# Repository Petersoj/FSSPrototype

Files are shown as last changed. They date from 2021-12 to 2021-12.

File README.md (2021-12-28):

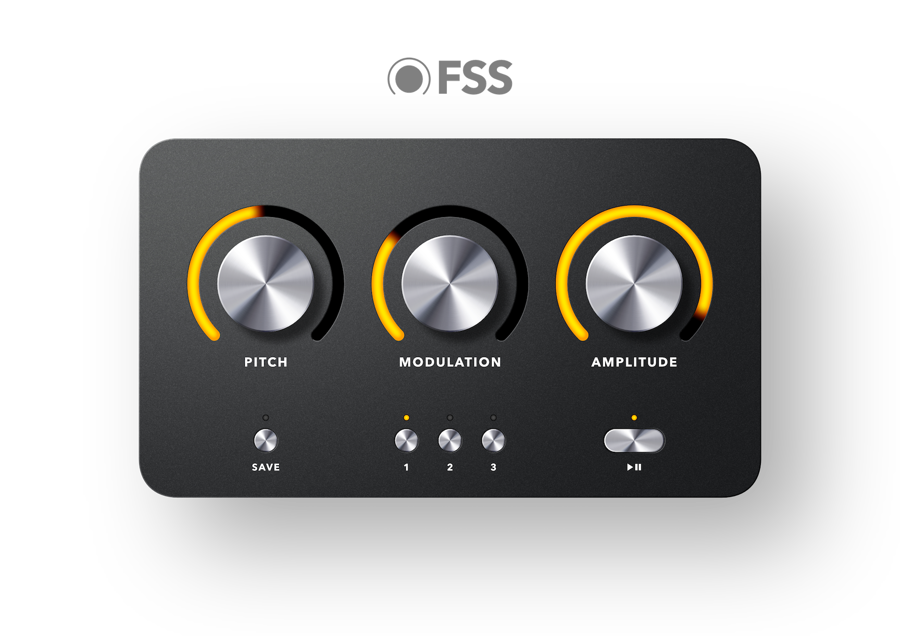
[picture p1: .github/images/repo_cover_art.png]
FSS prototype top-panel concept
<p align="center"></p>

# Fully-Synchronized Synthesizer (FSS) Prototype

This FSS prototype demonstrates the future of interfacing with a music synthesizer. Musicians often switch between programs on their synth as part of their creative process when experimenting with different sounds. However, the control knobs on their synth can't dynamically update to visually display the true value of that knob when switching between programs. This FSS prototype solves this issue by providing program-synchronized ring displays surrounding control knobs, along with internal components housed in a beautiful chassis, and interfaced with via a single USB cable. This repository contains various source files, design files, datasheets, and documentation relevant to the development of this prototype. This prototype serves as the final project for the Computer Design Laboratory ECE 3710 class at The University of Utah for Group 2. As a requirement for this class, this final project uses the [`CompactRISC16`](https://github.com/Petersoj/CompactRISC16) CPU and assembler that our group built as well. This CPU runs on an FPGA and executes our custom assembly code which is responsible for the FSS interface logic and communication. The FPGA board interfaces with the FSS prototype via I2C using a braided USB cable with the D+/D- pins adapted to be the SCL and SDA pins.

## Authors
- Jacob Peterson
- Brady Hartog
- Isabella Gilman
- Nate Hansen

## How This Repository is Organized
- [`.formatter/verilog/`](.formatter/verilog/) contains the Verilog source code formatter. More info on it [here](https://github.com/Petersoj/FSSPrototype#verilog-source-formatting-for-this-repository).
- [`CompactRISC16/`](https://github.com/Petersoj/CompactRISC16) is a git submodule of our custom CompactRISC16 (CR16) processor repository. Our FSS prototype firmware runs on this custom CR16 processor.
- [`assets/`](assets/) contains various asset files such as SolidWorks sketches and parts, dimension drawings for laser and water jet cutting, schematic and PCB files for our Main board and External board, pictures, etc.
- [`docs/`](docs/) contains our final project reports and Bill of Materials (BOM). Our final report is located [here](docs/Reports/Final%20Report/Final%20Report.pdf).
- [`resources/bram_init/`](resources/bram_init/) contains block RAM (BRAM) initialization files encoded in UTF-8 hexadecimal characters.
- [`resources/pin_assignments/`](resources/pin_assignments/) contains exported CSVs of pin assignments for the various Verilog top modules in this repository.
- [`src/asm/`](src/asm/) contains assembly source code files written in accordance with our custom CR16 ISA. More info on [`fss.asm`](src/asm/fss.asm) (the main program/firmware of our FSS prototype) can be found [here](https://github.com/Petersoj/FSSPrototype#assembling-fssasm).
- [`src/v/rtl/`](src/v/rtl/) contains the Verilog and SystemVerilog RTL code for our FSS prototype.
  - [`fss_top.sv`](src/v/rtl/fss_top.sv) instantiates BRAM, the External Memory interface module, and the CR16 processor. Additionally, it contains some logic to display various values on the 7-segment displays on the FPGA board and allows a user to address into BRAM using slide switches.
  - [`ext_mem.sv`](src/v/rtl/ext/ext_mem.sv) is the External Memory interface module which contains memory-mapping logic and instantiates the two peripherals that the FSS prototype requires: [`clock_divided_counter.sv`](src/v/rtl/ext/peripheral/clock_divided_counter.sv) which is used as a microsecond counter and [`i2c_bus.sv`](src/v/rtl/ext/peripheral/i2c_bus.sv) which is used to interface with the open-drain SCL and SDA bus lines for I2C communication.
- [`src/v/tb/`](src/v/tb/) contains the Verilog and SystemVerilog testbench code for testing the various FSS prototype RTL modules.

## Project Videos
We wanted to create a professional video in the form of a product advertisement showing the beauty we captured in the FSS prototype's design. That video is available [here](https://www.youtube.com/watch?v=7kbVaDARXf8). Additionally, a demo video showing the basic usage and functional overview of the FSS prototype is available [here](https://www.youtube.com/watch?v=SxbYaiAhI7I).

## Project Photos
<p align="center">
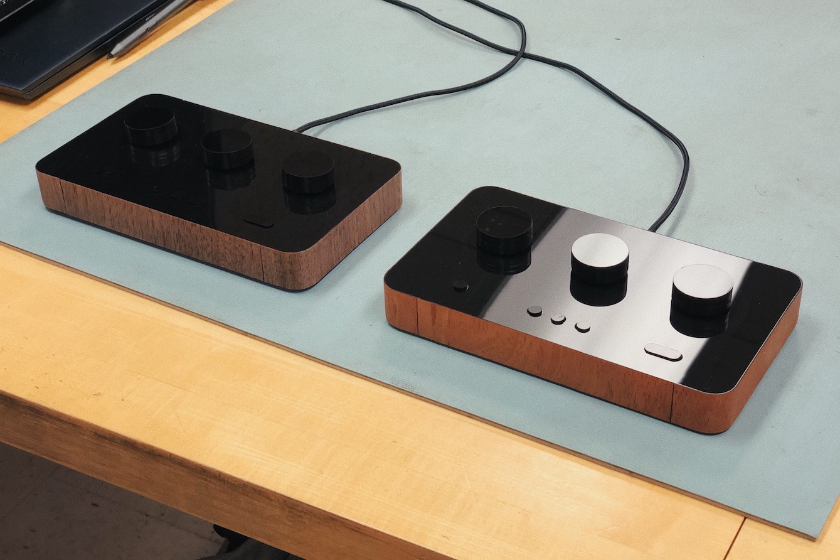
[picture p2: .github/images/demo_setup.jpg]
  
</p>
<p align="center">
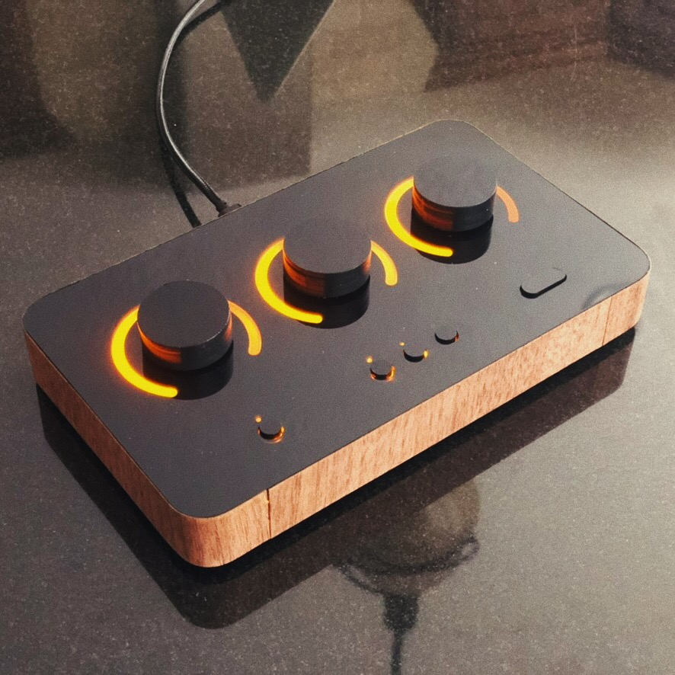
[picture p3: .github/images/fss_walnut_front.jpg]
  
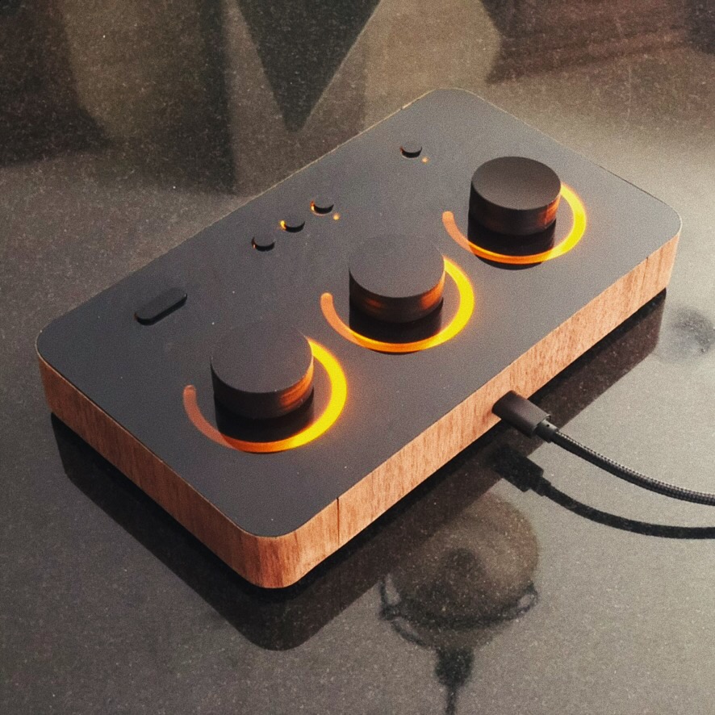
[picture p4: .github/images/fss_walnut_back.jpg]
  
</p>
<p align="center">
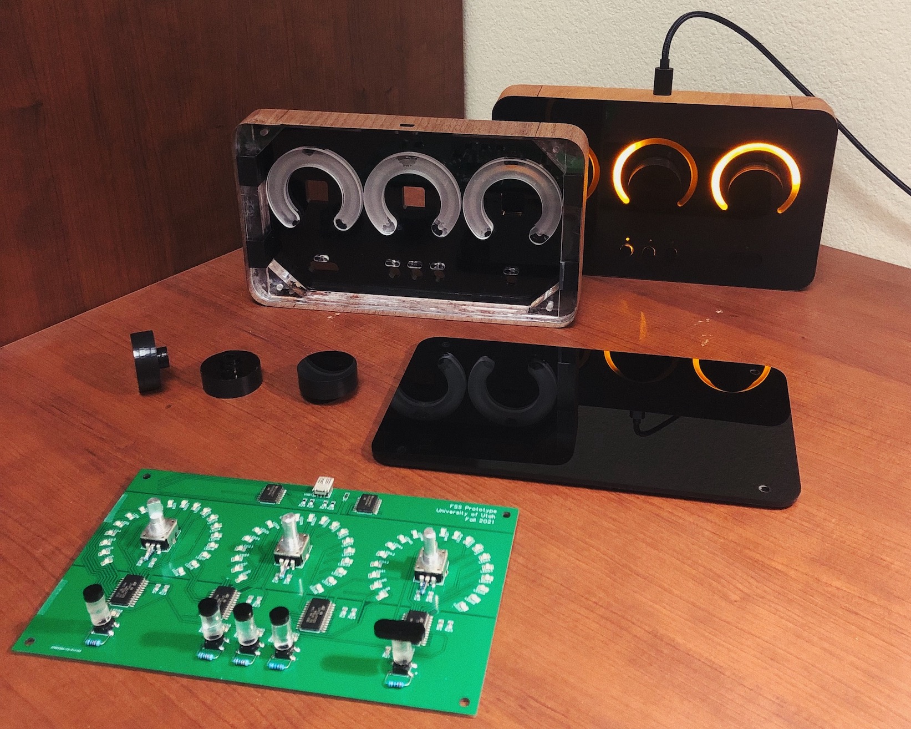
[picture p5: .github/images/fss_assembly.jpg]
  
</p>

## Assembling [`fss.asm`](src/asm/fss.asm)
[`fss.asm`](src/asm/fss.asm) contains the assembly source code for the firmware of the FSS prototype. This assembly source code is compiled to a [machine code data file](resources/bram_init/fss.dat) which is loaded into BRAM upon FPGA programming. To assemble/compile `fss.asm`, follow these steps:
1. Ensure that the `CompactRISC16` submodule has been initialized and updated via: `git submodule update --init`
2. Run the assembler via:
   ```
   ./CompactRISC16/assembler/assembler src/asm/fss.asm -o resources/bram_init/fss.dat -p 4096 -v 0 -b HEX
   ```
  * `-p 4096` sets the max padding lines to 4096 (which is 2^12 due to `fss_top` instantiating `bram` with a 12-bit address space) in the output machine code file
  * `-v 0` sets the padding line value to 0 (which initializes empty BRAM to all zeros) in the output machine code file
  * `-b HEX` sets the number base to hexadecimal in the output machine code file
3. More info about the CR16 assembler used in this project can be found [here](https://github.com/Petersoj/CompactRISC16#assembler).

## Verilog Source Naming Conventions and Format
- File names, module names, and wire/reg assignment names should be snake case (e.g. `my_verilog_module.v`)
- Testbench modules and file names should be appended with a `_tb` (e.g. `my_verilog_module_tb.v`)
- Top level modules and file names should be appended with a `_top` (e.g. `my_verilog_module_top.v`)
- There should only be one module per source code file
- Module instantiations should use uppercase named port lists with inputs prepended with `I_` and outputs prepended with `O_` (e.g. `my_verilog_module(.I_INPUT_1(my_input_1), .O_OUTPUT_1(my_output_1));`)
- Module signatures and bodies should use parameters instead of hard-coding constants. When defining the parameters for a module instantiation or for a module signature, the parameter list should start on the next line, but if there is only one parameter, it should be defined on the same line as the module instantiation or signature (same goes for the port list of a module).
- The port list in module signatures should contain `input` and `output` port direction declarations, as opposed to those port direction declarations being placed in the body of the module.
- Consecutive single line comments should always be aligned with eachother if there are no lines between them.
- If there are 2 or more consecutive lines (including no comments between the consecutive lines) that assign a `parameter`, `localparam`, `wire`, or `reg` to a constant or to a single-line expression, then the equals signs in those lines should be aligned.
- If a single-line expression/assignment needs to be split into multiple lines, then the following lines should be further indented by 8 spaces, or if the subsequent lines can fit within the 100 character column limit, then the subsequent lines should be further indented until they are aligned to the expression/assigment on the first line.
- No line should be greater than 100 characters.
- Use non-blocking assignments (e.g. `<=`) in sequential `@always` blocks and blocking assignments (e.g. `=`) in combinational `@always` blocks.
  - An `@always` block is sequential if it is sensitive to the `posedge` or `negedge` of an input signal, whereas it is combinational if it is sensitive to signals without the `posedge` or `negedge` modifier included in the sensitivity list.
- Module sections should generally follow the following format, from top of file to bottom of file:
  - Module signature with parameter list, then input wires, then output reg/wires
  - `localparam`s that defines constants for the rest of the module
  - Internal register and wire declarations
    - Prepend reg/wire names with `q_` to represent a 'current state' register/wire and `n_` to represent a 'next state' register/wire
  - Output mapping `assign` statements which map internal wires/registers with module output wires/registers
  - RTL logic with `assign` statements for all internal wires which generally consist of ternary operators
  - Module instantiations using named port lists in the instantiation signature and a module instance name that is the same as the module name (or a name that's more concise and applicable to the instantiation), but with `i` prepended
  - Clock `@always` blocks which generally should only include `posedge I_CLK` in the sensitivty list
  - Other `@always` (such as internal finite state machines) or `task` blocks

## Verilog Source Formatting For This Repository
To format verilog source code, use the [`istyle-verilog-formatter`](https://github.com/thomasrussellmurphy/istyle-verilog-formatter) tool via the `format` script:
```
.formatter/verilog/format <paths to files or directories>
```
For example, to recursively format Verilog source files in the `src` directory, use the following command:
```
.formatter/verilog/format src
```
The [`istyle-verilog-formatter`](https://github.com/thomasrussellmurphy/istyle-verilog-formatter) is used as a submodule in the [`.formatter/verilog`](.formatter/verilog) directory. Either clone this repository with `git clone --recurse-submodules` or use `git submodule init; git submodule update` to clone the `istyle-verilog-formatter` repository into the `.formatter/verilog` directory so that the `format` script can run properly. The `format` shell script will run `make` if the `iStyle` binary is not already present in the `istyle-verilog-formatter` directory. Note: you may need to make the script executable via: `chmod 755 .formatter/verilog/format`.

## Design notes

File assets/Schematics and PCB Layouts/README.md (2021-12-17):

The Breakout and Main schematic and PCB was creating using [easyEDA](https://easyeda.com).

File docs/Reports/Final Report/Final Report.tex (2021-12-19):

% Section Delegation Mapping:
%
% --------------------> Brady
% Introduction
% Overview
% --------------------
%
% Hardware
%   -FPGA Board ----------------> Nate
%   -Breakout Box --------------> Isabella
%   -FSS PCB -------------------> Jacob
%   -FSS Housing ---------------> Brady & Isabella
%
% CR16 Processor --------------->Nate
%
% --------------------> Jacob
% Peripheral Interfacing
% Assembler
% --------------------
%
% Firmware --------------------> Jacob & Nate
% Lessons Learned -------------> Everyone
%
% --------------------> Isabella
% About the Team
% Conclusion and Future Work
% --------------------

\documentclass[conference]{IEEEtran}
\usepackage{amsmath,amssymb,amsfonts}
\usepackage{algorithmic}
\usepackage{graphicx}
\usepackage{geometry}
\usepackage{textcomp}
\usepackage{xcolor}
\usepackage{array}
\usepackage{ragged2e}
\usepackage{multirow} % For multirows in tables
\usepackage{float} % Appending the [H] option forces the placement of a figure in the place it's in the code
\usepackage[numbers]{natbib} % For integration with bibliography commands
\usepackage{pdfpages}
\usepackage{hyperref}
\usepackage{chngpage}
\usepackage[utf8]{inputenc}
\usepackage{listings}

\usepackage{xparse}
\NewDocumentCommand{\code}{v}{%
\texttt{\textcolor{black}{#1}}%
}

\hypersetup{
    colorlinks=true,
    linkcolor=blue,
    filecolor=magenta,
    urlcolor=cyan,
    citecolor=magenta
}

\def\BibTeX{{\rm B\kern-.05em{\sc i\kern-.025em b}\kern-.08em
    T\kern-.1667em\lower.7ex\hbox{E}\kern-.125emX}}

\geometry{
    a4paper,
    left=0.5in,
    top=0.5in,
    right=0.5in,
    bottom=0.5in
}

\begin{document}

\begin{titlepage}
\begin{adjustwidth}{+1in}{+1in}
\begin{center}
    \vspace*{6.5cm}
    \Huge
    \textbf{Final Report: The Fully-Synchronized Synthesizer (FSS) Interface Prototype}

    \vspace{1cm}
    \LARGE
    Computer Design Laboratory ECE 3710\\
    Fall 2021\\
    The University of Utah

    \vspace{1cm}

    \normalsize
    \centering
    \begin{adjustwidth}{-1.5in}{-1.5in} % Adjust the L and R margins by 1 inch
    \begin{center}
        \begin{tabular}{ c c c c }
        \centering
        Jacob Peterson & Brady Hartog & Isabella Gilman & Nate Hansen\\
        \textit{Computer Engineering 2022} & \textit{Computer Engineering 2022} & \textit{Computer Engineering 2023} & \textit{Computer Engineering 2023}\\
        \textit{University of Utah} & \textit{University of Utah} & \textit{University of Utah} & \textit{University of Utah}\\
        Salt Lake City, UT & Salt Lake City, UT & Salt Lake City, UT & Salt Lake City, UT\\
        \end{tabular}
    \end{center}
    \end{adjustwidth}
\end{center}
\end{adjustwidth}
\end{titlepage}

\begin{abstract}
We present the design and implementation of a small-scale prototype for a fully-synchronized synthesizer (“FSS”) interface. The prototype is designed to address a major drawback of contemporary musical synthesizers. As a proof of concept for an innovative user interface, the prototype casts a vision for a more versatile and powerful synthesizer for the musical artists of tomorrow. Pursuant to the course objectives of ECE 3710, the principal component of the prototype is an Intel Cyclone V FPGA. This report chronicles our process of programming and interfacing with the FPGA as well as crafting a hardware system to deliver a prototype with a highly intentional and interactive user experience.
\end{abstract}

\section{Introduction}

In 1978 the music technology firm Sequential Circuits introduced the Prophet-5 musical synthesizer. Prophet-5 was among the world’s first \textit{fully-programmable} synthesizers, meaning that every controllable parameter could be stored in user-defined programs. Full programmability was a major milestone in the history of the synthesizer, and Prophet-5 would set the precedent of synthesizer design for decades to come.

In fact, over 40 years later, Prophet-5 remains the archetype of modern hardware synthesizers. Whereas the fully-programmable paradigm of Prophet-5 is highly useful, it suffers a major drawback. Fig. \ref{fig:param_analog} illustrates the drawback. In the fully-programmable paradigm, each parameter has both a \textit{physical value} and an \textit{active value}. The physical value is the value indicated by the position of the dial. The active value is set either by: 1) changing the position of the dial (in which case it is the same as the physical value); or by 2) recalling a user-defined program. Naturally, recalled values do not necessarily match—and in practice seldom do match—the physical values of the dials. We say that parameters controlled in this way are \textit{unsynchronized}.

\begin{figure}[bhtp]
    \centering
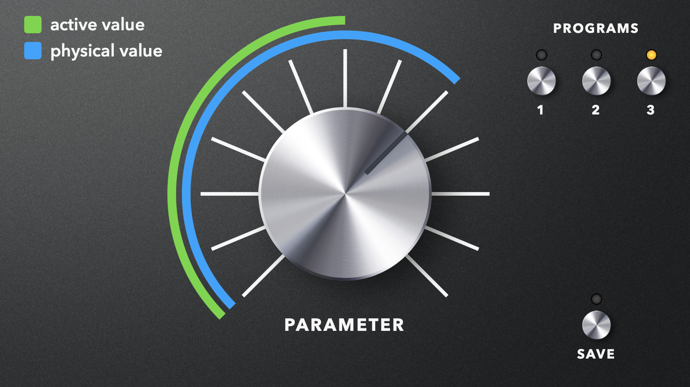
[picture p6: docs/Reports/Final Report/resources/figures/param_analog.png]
    
    \caption{The drawback with traditional, analog level meters. The physical and active values are out of sync!}
    \label{fig:param_analog}
\end{figure}

The drawback described above assumes the use of traditional, analog level meters as shown in Fig. \ref{fig:param_analog}. Fig. \ref{fig:param_digital} depicts a proposed alternative to the traditional level meter. This level meter consists of an LED ring display with digital control. By leveraging digital control, the level meter can display the active value of the parameter at all times, whether it is set by changing the dial or by recalling a program. We say that a parameter controlled in this way is \textit{synchronized}.

\begin{figure}[bhtp]
    \centering
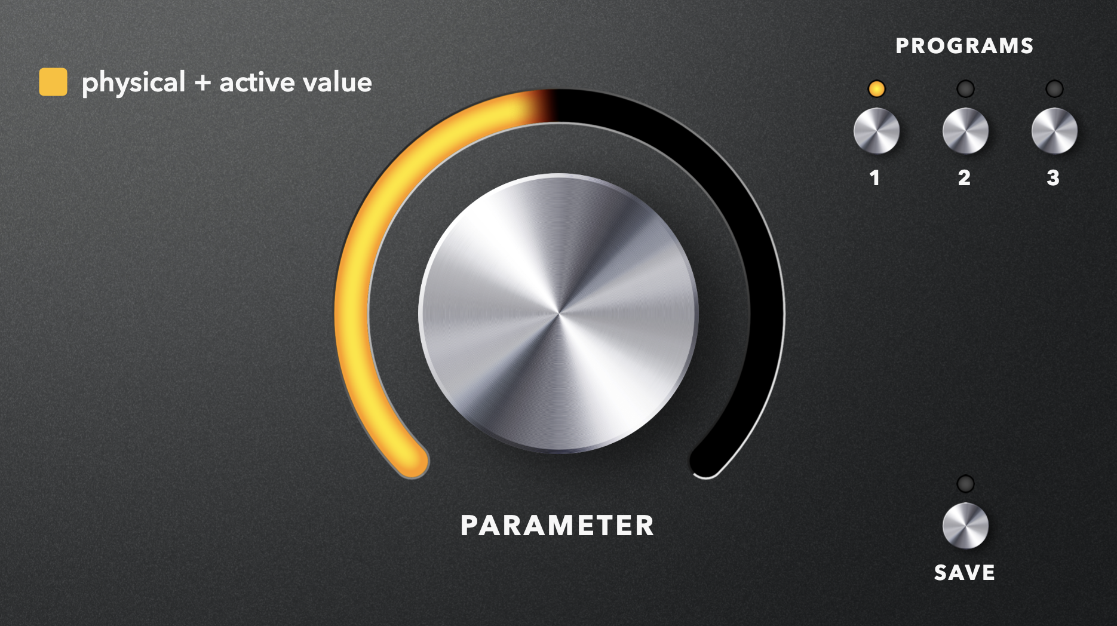
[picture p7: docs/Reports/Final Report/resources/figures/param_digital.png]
    
    \caption{The proposed digital level meter to implement synchronized parameters.}
    \label{fig:param_digital}
\end{figure}

We envision a musical synthesizer for which every parameter on the control panel is synchronized; such would be a \textit{fully-synchronized} synthesizer (``FSS'').

In this report we present the design and implementation of a small-scale prototype for an FSS interface (Fig. \ref{fig:fss_cover_art}) with respect to the learning objectives of ECE 3710. We believe our prototype is a successful proof of concept for the FSS interface as well as a clear, articulate, and creative application of our computer engineering skills to date. We hope you enjoy our presentation of the FSS interface prototype.

\begin{figure}[bhtp]
    \centering
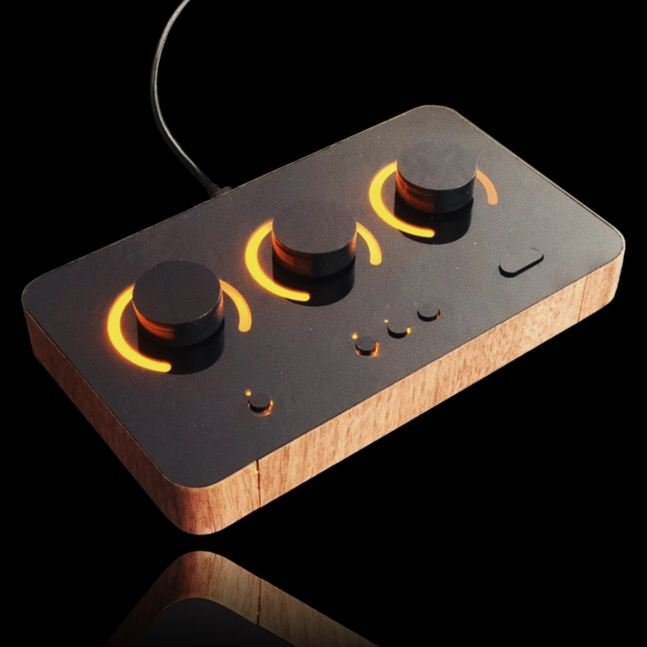
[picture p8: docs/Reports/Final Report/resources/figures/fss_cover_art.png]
    
    \caption{The FSS prototype.}
    \label{fig:fss_cover_art}
\end{figure}

\section{Overview}

The following is an overview of the user-facing functionality of the FSS prototype.

The FSS prototype has three synchronized parameters and three user-defined programs. The objective of the device is to demonstrate that all three parameters can be stored in each of the programs and recalled on demand.

Turning any of the parameter dials will change the value in its ring display by a corresponding amount. As soon as any parameter is changed beyond the programmed state, the save button LED turns on. The user may save their changes by pressing the save button, whereupon the save button LED turns off. The user may recall programs by pressing the corresponding program buttons.

The play/pause button is intended for auxiliary functionality, such as playing a sound if the FSS prototype is connected to an audio engine. In our implementation, the play/pause button is used to trigger animations of the display elements for aesthetic purposes.

\section{Hardware}
The hardware assembly of our device consists of 3 main components: A DE1-SoC Cyclone V FPGA board, a small breakout box for power supply and I$^2$C bus interfacing, and our FSS prototype device. These components and their connections can be seen at a high level in Fig. \ref{fig:full_fss_block_diagram}.

\begin{figure*}[bhtp]
    \centering
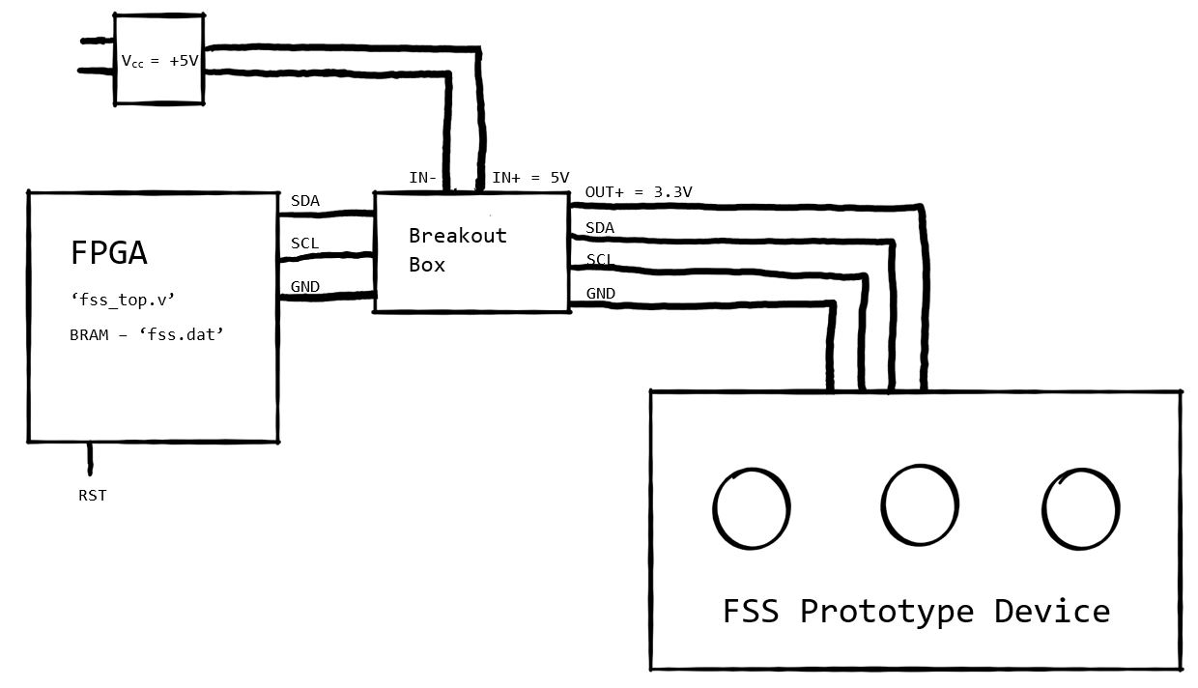
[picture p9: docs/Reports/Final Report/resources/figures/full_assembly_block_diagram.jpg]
    
    \caption{High level block diagram of the full FSS hardware assembly.}
    \label{fig:full_fss_block_diagram}
\end{figure*}

\subsection{FPGA Board}
The FPGA device drives all of the logical control for the FSS device. This is accomplished by instantiating a single module of our CR16 processor, and adding to that a set of peripheral modules. The modules that are peripheral to CR16 are responsible for allowing the assembly code access to important device data such as the state of the buttons and rotary encoders, the state of the LED indicators, and a 48-bit microsecond counter for I$^2$C timing. All of these modules were coded in SystemVerilog HDL and are available within the GitHub repository ``FSSPrototype.'' The FPGA acts as an I$^2$C master, where GPIO pins 1 and 2 are the SCL and SDA lines respectively, as shown in Fig. \ref{fig:gpio_mapping} The FPGA is also attached to a common ground shared by the FSS prototype device and the breakout box. In order for the device to function, the FPGA is programmed with the FSS prototype Verilog modules (\code{fss_top.sv} being the top-level module), the CompactRISC16 (CR16) Verilog modules, and a block RAM (BRAM) initialization file containing the machine code of our firmware.

\begin{figure*}[bhtp]
    \centering
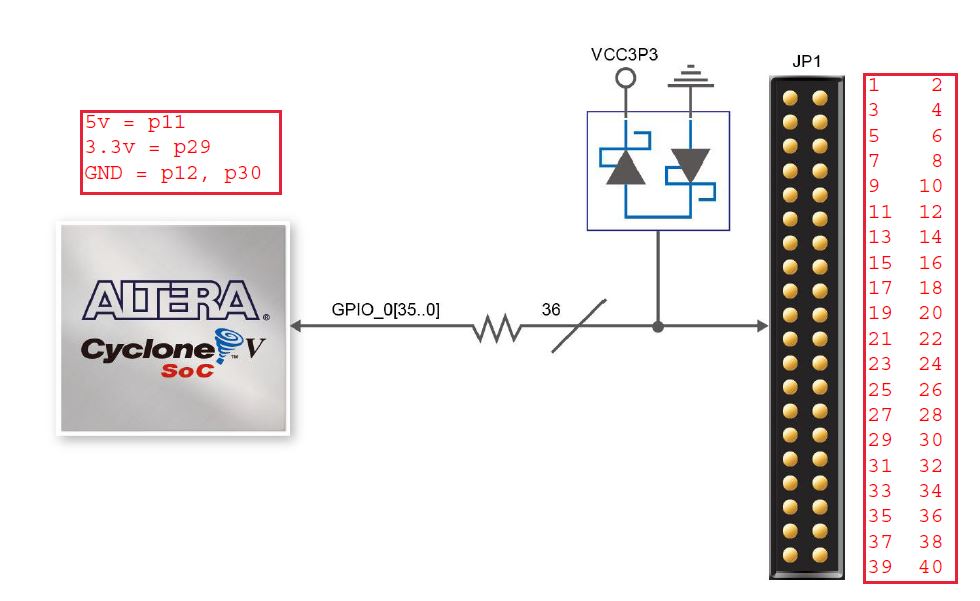
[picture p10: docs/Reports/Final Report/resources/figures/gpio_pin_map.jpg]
    
    \caption{GPIO pin diagram as obtained from the Cyclone V user manual with mappings added \cite{cite:de1-soc_manual}.}
    \label{fig:gpio_mapping}
\end{figure*}

The FPGA device allowed our team to employ a variety of useful testing methods, such as displaying data from BRAM on the bank of seven-segment displays with the slide switches acting as the BRAM address, assigning an FPGA button to a global reset, and testing I$^2$C communication. Our device relies on the internal 50MHz clock on the FPGA board, but we could also slow down runtime execution during debugging by tying the clock signal to a push button. Successful design and testing of this project relied on substantial interfacing with the FPGA.

\subsection{Breakout Box}
The breakout box is responsible for powering the FSS prototype interface as well as forwarding the I$^2$C signal coming from the FPGA to the port expander chips on the main PCB. The housing of the breakout box contains a USB type-A receptacle, a USB type-B receptacle, 2 male pin headers, a buck converter, and a rocker switch. The USB type-B receptacle is responsible for receiving power from the USB cable voltage bus and delivering it to the breakout PCB and then the main PCB. This power cable supplies 5V to the board from a DC power source, which is generally a wall adapter plugged into a standard outlet. From here the voltage is stepped down to 3.3V by a DC-DC buck converter contained within the breakout box to ensure the main PCB is receiving an operating voltage of 3.3V. Then, the USB type-A cable supplies this power to the main PCB board. To make control of power simple, the breakout box also includes a rocker switch that toggles the power on and off.

The control logic sent by the FPGA is also routed through the breakout box. The FPGA drives the I$^2$C bus lines, both SDA (serial data) and SCL (serial clock), using the GPIO PMOD pin headers on the FPGA board with an open-drain configuration. Breadboard wires then connect the two bus lines from the FPGA board to the breakout box, and the breakout PCB routes the two bus lines to the USB type-A cable which is then connected to the FSS prototype. The USB type-A cable's D+ and D- differential data lines are adapted to be the SCL and SDA signals of the I$^2$C bus respectively.

The breakout board schematic and PCB layout are shown in Figures \ref{fig:breakout_schematic} and \ref{fig:breakout_pcb} respectively.

\begin{figure*}[bhtp]
    \centering
    
    \caption{Schematic of Breakout PCB.}
    \label{fig:breakout_schematic}
\end{figure*}

\begin{figure*}[bhtp]
    \centering
    
    \caption{Layout of Breakout PCB.}
    \label{fig:breakout_pcb}
\end{figure*}

\subsection{FSS PCB}
The FSS prototype's PCB is responsible for all the electronic circuitry on the device. In this document, we refer to this PCB as the ``main'' PCB and it resides within the prototype's housing. We wanted to preserve the beauty factor of our FSS prototype, so instead of using many breadboard wires to interface the main PCB to the FPGA board, we opted to use a single USB cable that is inserted into the back of the prototype's housing. A USB Mini type-B receptacle connects this USB cable from the breakout box to the main board, and is used to provide power throughout the board and, as mentioned previously, adapts the D+ and D- differential data lines as the SCL and SDA signals of the I$^2$C bus. All communication from the FPGA to the main board must take place serially since it's impractical to drive the board's components individually using the PMOD pin headers on the FPGA board. So, to drive the board's components serially, the \code{GMSB0522102Y7EU} 8-bit I/O port expander IC is used. Two of these port expander chips in conjunction provide complete I/O to the entirety of the main PCB and the serial communication protocol to interface with them is I$^2$C in standard mode ($100$ kHz clock speed). This port expander chip is quasi-bidirectional, meaning that there is no configuration register to specify whether a port is an input or an output. Instead, to use a port as an input, the port is driven high and can be pulled low by an external component. 5 tactile push buttons with a pull-up configuration are connected to one of the I/O port expander chips. Additionally, there are 3 quadrature-encoded, mechanical rotary encoders each with two channels --- A and B. The individual channels use a pull-up configuration and are connected to one of the I/O port expander chips. These two channels in conjunction make up the quadrature-encoded output of these rotary encoders.

The FSS prototype contains 62 LEDs with an amber hue. There are 19 LEDs in each of the 3 ring displays and 1 LED for each of the 5 button indicator lights. To drive all of these LEDs using minimal I/O, 4 of the \code{STP16CPC05MTR} 16-bit, latching, shift-register LED driver ICs are used. Each driver contains the following pins: \code{SDI} (serial data in) which the input to the shift register, \code{SDO} (serial data out) which contains the bit shifted out of the shift register, \code{CLK} (clock) which synchronizes \code{SDI} and \code{SDO}, \code{LE} (latch enable) which latches the driver output when asserted, \code{OE} (output enable) which is the active-low enable pin, and \code{R-EXT} which controls the chip's internal current limiter to provide a constant-current source to the LEDs. These 4 LED driver ICs on the main board are daisy-chained together and the first driver in the chain has its \code{SDI} pin connected to one of the ports on the I/O port expander chip. Additionally, one of the I/O port expander chips drives all 4 \code{CLK} and \code{LE} signals of the LED drivers so that they are all synchronized.

The SDA and SCL lines of the I$^2$C bus are short-circuit protected using $300 \Omega$ series resistors. This resistance is low enough that it does not affect the I$^2$C bus capacitance, which is limited to $400$ picofarads in standard mode. Additionally, the 6 ft. braided USB cable used to interface with the main board is shielded, has a low resistance, and a low parasitic capacitance, so the I$^2$C bus timing requirements are met without an issue. As part of the I$^2$C specification, the SDA and SCL lines are directly connected to 3.3V using two $2 \text{k}\Omega$ pull-up resistors.

As another precaution, series resistors are used to protect against accidental short-circuits on the pull-up/pull-down inputs of the I/O port expander chip. In the event that a quasi-bidirectional port that is treated as an input is accidentally driven low via I$^2$C, a short-circuit can occur if a pull-down input configuration is pulled high --- directly connecting a logical high to a logical low with no series resistance.

The ECAD tool used to create the schematics and PCB layouts is called \href{https://easyeda.com}{easyEDA}, an online cloud-based PCB design tool. The Gerber files were exported from easyEDA and uploaded to JLCPCB, our PCB fabricator of choice. This process was done for both the main board and the breakout board schematic and PCB. We also ordered an SMT stencil for our main PCB which allowed us to apply solder paste to the SMD pads efficiently. We then placed the various SMD components onto the solder paste areas accordingly and reflowed the components using a reflow oven.

The main board schematic and PCB layout are shown in Figures \ref{fig:main_schematic} and \ref{fig:main_pcb} respectively. Additionally, Figure \ref{fig:main_pcb_assembly} shows a picture of the final PCB assembly.

\begin{figure*}[bhtp]
    \centering
    
    \caption{Schematic of main PCB.}
    \label{fig:main_schematic}
\end{figure*}

\begin{figure*}[bhtp]
    \centering
    
    \caption{Layout of main PCB.}
    \label{fig:main_pcb}
\end{figure*}

\begin{figure*}[bhtp]
    \centering
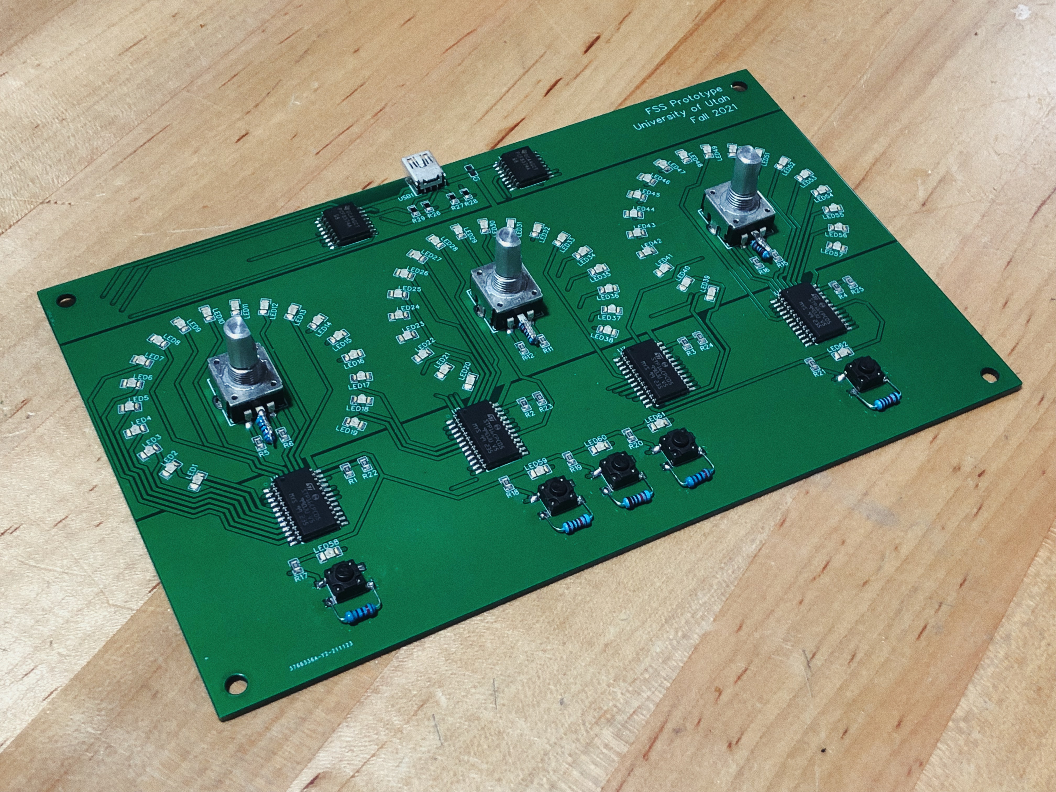
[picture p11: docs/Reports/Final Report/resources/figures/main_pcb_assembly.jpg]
    
    \caption{Picture of main PCB assembly.}
    \label{fig:main_pcb_assembly}
\end{figure*}

\subsection{FSS Housing}
For the external housing, our team decided to go with a minimal design. The final assembly was constructed from stacked layers of acrylic panels, providing a solid structure with pleasing weight. The top layer was a sheet of translucent black acrylic, which allowed for our LED to shine through in a low amber color. Veneer surrounds the perimeter of the housing, giving a more natural feeling to the box. Finally, the knobs and control buttons were constructed out of acrylic to give them that same weight and sleek feeling the rest of the synthesizer gives. This design is minimal, but gives the user a sense of quality. By following a design process that takes the user's needs into account, we were able to implement a device that is equal in both form and function. The final result has the quality and professional feeling that is geared toward musicians and producers.

The internals of the FSS housing can be seen in Figure 8. This picture is of an older version where we had used plywood for the internal layers, before we replaced them with acrylic.

\begin{figure*}[bhtp]
    \centering
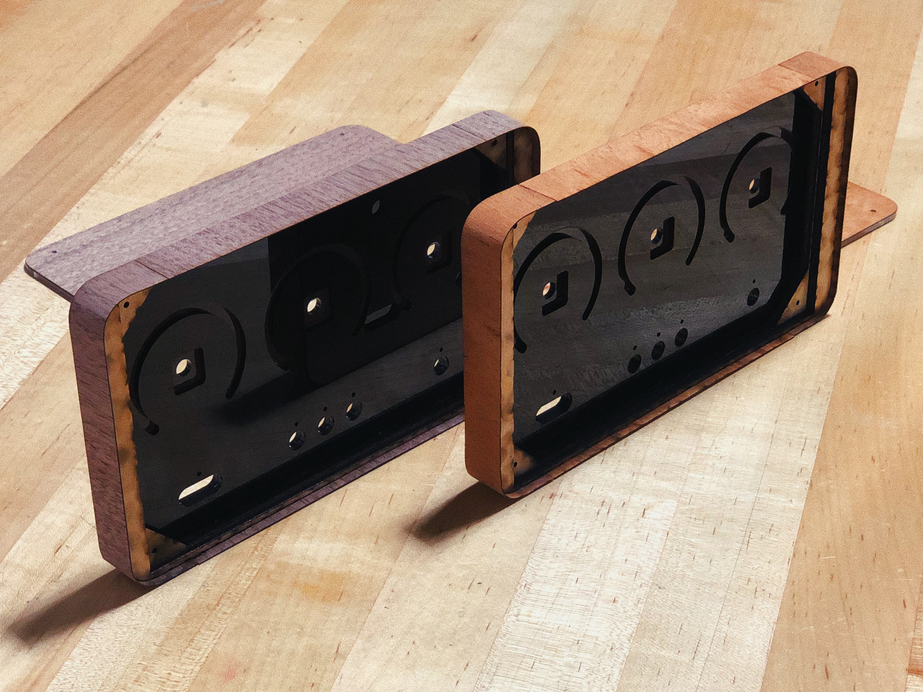
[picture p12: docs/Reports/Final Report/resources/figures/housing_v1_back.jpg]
    
    \caption{Picture of FSS housing backside.}
    \label{fig:fss_walnut_front}
\end{figure*}

\section{CR16 Processor}
The details of our CR16 processor are contained in the previous lab reports, but for the purposes of the FSS prototype's interface firmware, it would be enlightening to review some of the aspects of our CR16 ISA that were implemented specifically to abstract away some of the complexity in writing assembly code. Although the processor we designed is mostly equipped for RISC instructions, these added instructions may have more of a CISC ``feel'' to them. The FSM controller of the CR16 CPU manages the fetch-decode-execute procedure for these instructions in the same way as the other instructions. Most of these instructions could be replaced by a series of RISC instructions, but we saved clock cycles by implementing their behavior into the CPU FSM. Each of the following instructions is accompanied by an explanation for their implementation:
\begin{enumerate}
    \item \verb|LOADX/STOREX|: These instructions are external \verb|LOAD| and \verb|STORE| instructions which will be capable of loading and storing data directly into an external memory bank. This was implemented for two reasons. We want \verb|LOAD| and \verb|STORE| to have access to the whole address space of BRAM, and we want to be able to communicate in a modular way with GPIO registers that are sending and receiving information from the FSS GPIO port expanders over I$^2$C. These instructions also allow us to read a value from the microsecond counter, which is a separate Verilog module we created to assist with timing. Details on these modules are explained in the ``Peripheral Interfacing'' section.
    \item \verb|CALL/CALLD/RET| \textit{instead of} \verb|JAL/JUC|: Our firmware is quite complex, and, for ease of development, we planned to push and pop instruction addresses on and off the stack to manage nested subroutine calls. It seems to make more logical sense to encapsulate the management of the return address within the instruction. The \verb|CALL| and \verb|CALLD| (\verb|CALL| with displacement) instructions manage the return address implicitly, and \verb|RET| will be an unconditional jump to the previously calculated return address, which is popped off the stack. This way, we don't need a dedicated register for the return address of a subroutine call.
    \item \verb|PUSH/POP|: These instructions encapsulate the behavior of modifying the stack pointer and loading/storing data on the stack. In order for them to work properly, the first few instructions of any program that is run on the CR16 processor must assign an address to the stack pointer register \code{rsp}. By convention, the stack starts at the highest memory address and grows downward. The stack ``lives'' in the same file as the code, so its capacity is between the EOF and the final machine-encoded instruction. Our processor has no kernel, and therefore has no notion of segmentation faults, so stack overflow has unintended and sometimes sneaky consequences.
\end{enumerate}

 The full ISA is located in the appendix of this document. This ISA may seem unconventional, and differs from most standardized ISAs that fall cleanly into CISC or RISC categories. However, by the process of formulating our ISA, we have learned much about the considerations computer architects must make when designing an ISA. Our final CR16 ISA was assembled with a lot of careful thought and effort. The assembly software was a burdensome aspect of our project, so we are glad we had these features to develop it intuitively and cleanly.

\section{Peripheral Interfacing}
There are two peripherals that our FSS prototype's firmware communicates with using the \code{LOADX/STOREX} instructions: the I$^2$C bus and a microsecond counter. The I$^2$C bus simply consists of two open-drain I/O pins --- one for SCL and one for SDA. These ports use the \code{inout} port direction in SystemVerilog to designate them as being used as both an input and an output. To create the open-drain configuration for these pins, the following Verilog code is used:
\begin{verbatim}
assign O_SCL = I_SCL_T ? 1'bZ : 1'b0;
assign O_SDA = I_SDA_T ? 1'bZ : 1'b0;
\end{verbatim}
This essentially creates two ground-driven, tri-state buffers with inverted triggers.

The microsecond counter is simply a clock divider in conjunction with 48-bit counter. Knowing that our CR16 processor clock uses our FPGA board's $50$ MHz clock, we can divide that by $50$ to create a clock signal with a period of 1 microsecond. Then with every pulse of the divided clock signal, a counter increments by 1.

These two peripherals are SystemVerilog modules that are instantiated in a another SystemVerilog module entitled \code{ext_mem}. This module maps addresses from the CR16 external memory port to the various external peripheral instantiations, namely: \code{clock_divided_counter} and \code{i2c_bus}. When the \code{LOADX/STOREX} instructions are decoded in the CR16 processor, the external memory port addresses into the peripheral instantiations accordingly so that 16-bit values can be read or written to directly from our assembly code. This is very similar to how memory-mapped I/O is done in commercial-grade microcontrollers and SoCs.

\section{Assembler}
Our CR16 processor project includes an accompanying custom-built assembler to compile assembly code written in our specialized ISA. The assembler itself is written in Java and uses the Gradle build tool for dependency management and distribution building. A library entitled ``JCommander'' is used to handle command-line argument parsing seamlessly. Listing \ref{listing:assembler_command_line} shows the command-line usage of our assembler.
\begin{figure*}
  \begin{lstlisting}
  Usage: assembler [options] <assembly code file path>
  Options:
    -d, --debug
      Turns on debug mode.
      Default: false
    -p, --max-padding-line
      The line number to which padding lines should be added to an output
      binary.
      Default: 0
    -v, --max-padding-line-value
      The decimal value of the padding lines.
      Default: 0
    -b, --number-base
      The number base of the output binary.
      Default: HEX
      Possible Values: [BINARY, DECIMAL, HEX]
    -o, --output
      The output binary file path. Defaults to <input assembly file>.dat.
    -s, --output-processed
      True to write the processed assembly to <output binary file
      path>.processed.asm.
      Default: false
  \end{lstlisting}
  \caption{Command-line usage of CR16 Assembler.}
  \label{listing:assembler_command_line}
\end{figure*}

When run, the input file is read into memory and the code lines are sanitized, meaning that all code comments and unnecessary whitespace is removed. Comments in our assembly syntax are delimited using the hashtag symbol (e.g. ``\#''). Then macros are indexed and processed. A macro is used to create a mapping between a string (the key) and another string (the value). The following shows an example of how a macro is used in our firmware assembly code to define the upper and lower 8-bits of the stack pointer:
\begin{verbatim}
# Initialize the stack pointer at BRAM
# address 0x0FFF (which is 2^12 - 1)
`define STACK_PTR_LOWER 0xFF
`define STACK_PTR_UPPER 0x0F
\end{verbatim}
Macros are used in several places in our firmware assembly code as they are primarily used to give names to numerical constants.

Once macros have been processed, labels are then indexed and processed. Labels are used to reference arbitrary static memory addresses, which allows a programmer to declare named functions and define static memory blocks. Listing \ref{listing:assembly_code_labels} following shows an example of how labels are used in our firmware assembly code. This example listing contains an \code{.array_copy} function implementation that's prepended with our ``AssemblyDoc'' code documentation. Note that the assembler will compile the \code{JLO .array_copy:loop} line to a branch instruction since the \code{.array_copy:loop} label is within the branch instruction's displacement range (which is $\pm127$). Similarly, a \code{CALL} instruction will compile to a \code{CALLD} instruction in the event that the given label is within the \code{CALLD} instruction's displacement range (which is $\pm2048$). Also note that if a programmer uses a \code{CALL} or jump instruction and the desired label to call/jump to lies outside the displacement range of the equivalent displacement instruction, then the assembler will force the programmer to use an ``address loading register'' with the following syntax: \verb|JLO .far_away_label$r0|. In this example, the absolute memory address of \code{.far_away_label} will be loaded in register \code{r0}. This forces the programmer to make a conscience decision about which register a label address should be loaded into via the \code{MOVIL} (move-immediate for lower 8-bits) and \code{MOVIU} (move-immediate for upper 8-bits) instructions.
\begin{figure*}
  \begin{lstlisting}
##
# Copies the array at 'r11' to 'r12' with length 'r13'.
#
# @param r11 - a pointer to the array to copy from
# @param r12 - a pointer to the array to copy to
# @param r13 - the number of words to copy
#
# @return void
##
.array_copy
    MOVIL   r0  0x00
    MOVIU   r0  0x00

    .array_copy:loop

    LOAD    r5  r11
    STORE   r12  r5

    ADDI    r11 1
    ADDI    r12 1

    ADDI    r0  1
    CMP     r0  r13
    JLO     .array_copy:loop

    RET
  \end{lstlisting}
  \caption{The ``.array\_copy'' function from our firmware assembly code.}
  \label{listing:assembly_code_labels}
\end{figure*}

Finally, the assembler will map all the instructions to their machine code equivalent as the CR16 ISA specifies. This machine code file is written according to the command-line arguments as shown in Listing \ref{listing:assembler_command_line}.

\section{Firmware}
The following sections discuss the functionality of our firmware assembly code. We divided complex functions into smaller subroutines, allowing for the complexity of our firmware to be abstracted away piece-by-piece. This makes the assembly code much easier to read and is good programming practice.

\subsection{I\hspace{0.25mm}\texorpdfstring{$^{\textit{2}}$} CC Logic}
To interface with the I/O port expander chips via I$^2$C, a number of subroutines to handle writing and reading to and from the I$^2$C bus were programmed. Some simple ``getter'' and ``setter'' functions were created for the binary values of SDA and SCL lines. Then \code{START} and \code{STOP} conditions were programmed into separate functions to take control and release the bus respectively. A function for getting the acknowledge (ACK) bit from a slave and a function for sending the not-acknowledge (NACK) bit to a slave were also programmed. Lastly, functions for reading and writing arbitrary bits on the bus lines were programmed.

These simpler subroutines are called sequentially in the \code{.i2c_read_byte} and \code{.i2c_write_byte} functions. These function signatures are shown in Listings \ref{listing:assembly_i2c_read} and \ref{listing:assembly_i2c_write} respectively. The argument list, as shown in the function's AssemblyDoc, gives a sense of how easily it is to read and write a byte to an addressable slave on the I$^2$C bus from anywhere in our firmware assembly code. Note that in our setup, the FPGA board serves as the I$^2$C bus master and the I/O port expander ICs serve as the slaves. More information on the I$^2$C protocol can be found \href{https://en.wikipedia.org/wiki/I\%C2\%B2C}{here}.
\begin{figure*}
  \begin{lstlisting}
##
# Requests to read a byte from a slave on the I2C bus.
#
# @param r11 - the 7-bit address of the I2C slave
#
# @return r10 - the byte read from the I2C bus or '0x0100' if a byte could not be read
##
.i2c_read_byte
  \end{lstlisting}
  \caption{The ``.i2c\_read\_byte'' function signature from our firmware assembly code.}
  \label{listing:assembly_i2c_read}
\end{figure*}
\begin{figure*}
  \begin{lstlisting}
##
# Requests to write a byte to a slave on the I2C bus.
#
# @param r11 - the 7-bit address of the I2C slave
# @param r12 - the byte to write to the I2C slave
#
# @return r10 - 1 if successful, 0 if byte could not be written
##
.i2c_write_byte
  \end{lstlisting}
  \caption{The ``.i2c\_write\_byte'' function signature from our firmware assembly code.}
  \label{listing:assembly_i2c_write}
\end{figure*}

\subsection{Microsecond Counter}
The microsecond counter module was added as a distinct Verilog module. The counter is 48 bits wide, and acts like a peripheral to the FSS device. We determined this to be a necessary bit width because $2^{32}$ microseconds is only about 71 minutes, and the software could misbehave if the counter ever resets. Since $2^{48}$ microseconds is about 8.9 years, the counter should never reset while the device is operating. Because the counter acts like a peripheral, its 48-bit count is stored in a set of 3 discrete 16-bit registers which can be loaded into the processor's regfile using the \verb|LOADX| instruction. When the microsecond counter data is fetched, it can be used to store timestamps and calculate elapsed time. This is only feasible if the software can accommodate 48-bit unsigned subtraction. Thankfully unsigned subtraction and 2's complement subtraction are congruent. Therefore, we can use the \verb|SUB| instruction to subtract the least significant bits first, and then propagate any borrows to the next most significant bits. A borrow will never occur out of the MSB since the time elapsed will usually never reset to a lower number.

The most significant advantage of this functionality is that we can implement a helper function in the assembly that ``sleeps'' the processor by a certain number of microseconds. This behavior is imperative to ensure correct protocol behavior with I$^2$C communication and LED animations.

\subsection{Rotary Encoder Polling}
To retrieve the state of the three rotary encoders, the port expander chip connected to the rotary encoder channel pins is polled and a decoding function is called to determine its rotational direction --- either clockwise or counter-clockwise. Our chosen rotary encoders output a quadrature-encoded signal. Quadrature encoding is performed using two distinct bit values, where each value represents the state of a channel in the rotary encoder device. Fig. \ref{fig:rotary_encoder_schematic} shows the schematic of our rotary encoders with a suggested filter circuit. From a high level, the rotational direction can be determined by the appearance of the timing diagram for the two distinct signals. Fig. \ref{fig:quadrature_encoding} illustrates how a timing diagram may look when turning a rotary encoder in the clockwise direction, given that terminal A is the upper waveform and terminal B is the lower waveform.

\begin{figure}[h]
    \centering
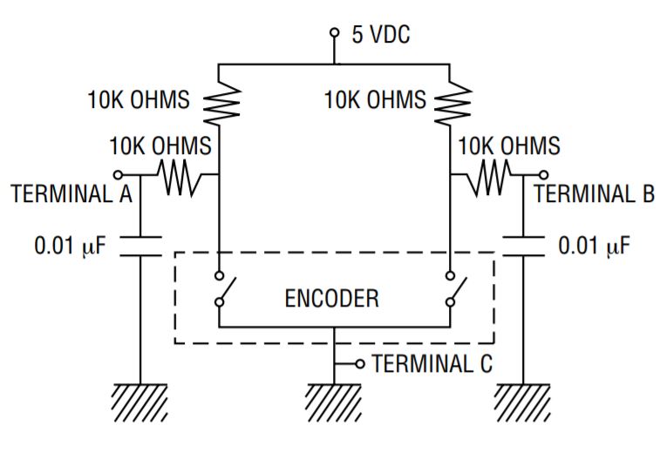
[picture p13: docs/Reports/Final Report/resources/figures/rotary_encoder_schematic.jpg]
    
    \caption{Schematic for PEC11R Series rotary encoders as seen in \cite{cite:rotary_encoders}}
    \label{fig:rotary_encoder_schematic}
\end{figure}

\begin{figure}[h]
    \centering
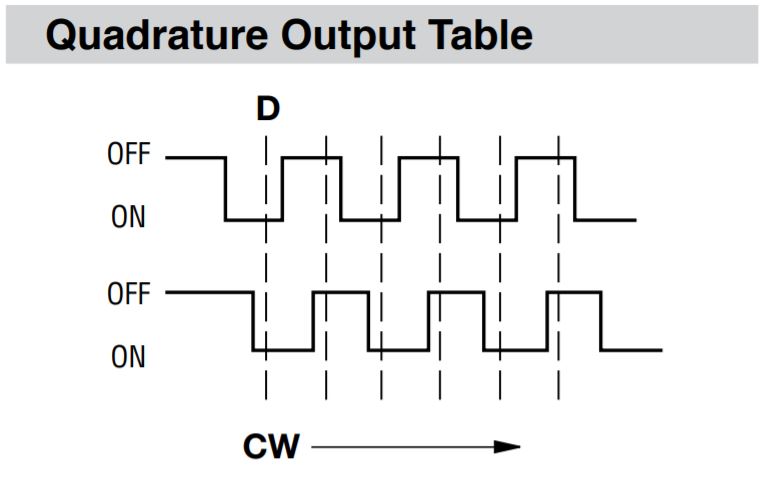
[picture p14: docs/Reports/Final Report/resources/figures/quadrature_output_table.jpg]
    
    \caption{Waveform for a quadrature-encoded signal as seen in \cite{cite:rotary_encoders}}
    \label{fig:quadrature_encoding}
\end{figure}

The assembly code uses a static memory address in BRAM to store the previously obtained state of each rotary encoder, and the ``decode'' functions works to detect whether or not the rotary encoder has traversed a whole period of the quadrature output waveform. If it has, then the control knob has been moved far enough to turn on or off an LED in the ring display.

\subsection{LED Animations}
One of our goals was to interface with the audio codec on our FPGA boards to generate sound, just as a commercial music synthesizer would, although, this goal was secondary. Due to time constraints, we instead implemented some very cool animations for the LEDs in the ring displays on the FSS prototype. That includes a start up animation and 5 ``idle'' animation sequences. The pause/play button on the FSS was originally intended to pause and play the sound generated by the audio codec, but is now used to toggle between the various ``idle'' animation sequences. Some of these sequences programatically shift a certain number of 1's and 0's into the LED driver shift register with various delays. Other animation sequences use frame data located in static memory. These frames are encoded with the values (0 - 19) of the 3 ring displays and an animation execution function, entitled ``\verb|.execute_animation_sequence|'' steps through the frames with a 2 millisecond delay, decoding the frame and updating the LED driver shift registers accordingly.

\subsection{Business Logic and Final Device Integration}
With all of the sophisticated communication and data processing abstracted away, the business logic of the main routine actually becomes quite simple. On initialization, the FSS ring displays light up with a brief startup animation. When the animation finishes, the FSS program loads program 1. The default program values are hard-coded into the firmware in a static location in memory which is referenced with a label. Because the FPGA must be reprogrammed every time it is turned off, we do not yet have a way to allow saved programs to persist after shutdown, thus the saved program values only persist throughout program runtime. The firmware then enters into an infinite loop which integrates all the logic explained above to poll the state of the inputs from buttons and rotary encoders, process that data, and push the correct chain of values into the LED driver shift registers. All of this occurs in a short time period, so no concurrency or event listening is necessary. The user receives practically instantaneous feedback to any stimulus applied to the dials or buttons.

\section{Lessons Learned}
As a team, we feel that we have acquired many skills from the work we had to do for this project. Some of the most memorable lessons are learned when we make mistakes, and we would like to address a number of those lessons. These concepts apply to the software, electronics, and physical assembly aspects of our project, as well as our project management skills.

\begin{enumerate}
  \item Schematic Imperfections: Unfortunately, we added a series resistor in the wrong place to our push button and the rotary encoder channel pull-down configurations on our main PCB. Due to the fact that we were so concerned about accidentally shorting our I/O port expander chips, we placed resistors for short-circuit protection instead of resistors for normal operation. This issue was rectified easily by soldering through-hole resistors in series to the push button and rotary encoder channel pull-down configurations.
  \item Common Ground: We neglected one important detail about I$^2$C when we designed our breakout PCBs --- all masters and slaves on the bus need a common ground. The \code{GND} wire as shown in Figure \ref{fig:full_fss_block_diagram} was added after the PCBs were fabricated since the I$^2$C requirement of a common ground was neglected during the schematic development process. This issue was easily rectified by soldering a wire to the \code{OUT-} pin of the buck converter which could then be connected to the FPGA board's ground pin on the PMOD pin header.
  \item Rotary Encoder Filter Circuit: The datasheet for our rotary encoders contains a schematic for a suggested filter circuit, as seen in Fig. \ref{fig:rotary_encoder_schematic}. We didn't implement this filter circuit under the impression that, due to our sampling period, the rotary encoder channels would be ``pseudo-debounced.'' During the hardware debugging process however, we observed some noise around the channel transition thresholds, and we believe that a combination of the filter circuit and software debouncing would alleviate this issue.
  \item Water Jet Issues: Our first design was to utilize an anodized aluminum plate for the top panel of the device. We contracted a company here in the Salt Lake Valley to use a water jet to route out the windows for the LED lights and push buttons. When we received the plates, there was evidence of a low-quality water jet job, with imprecise cuts and extremely rough edges. This was a disappointing waste of time, money, and materials. To combat this, we could have invested time in visiting the facility to view samples of the water jet work on anodized aluminum before committing to have them do our work.
  \item Wood is an Unreliable Material: Wood dimensions are not always as advertised depending on the climate and humidity of the supplier. In our particular application, the wood layers were too thin, and bowing made the assembly process unnecessarily difficult. Real wood veneer was also quite fragile, though the aesthetic was pleasing.
  \item Acrylic is an Higher-Cost Material: To compensate for the challenges we faced with wood, we built the walls of the housing using layers of laser-cut acrylic sheets. This resulted in significant material waste, and was much more expensive than wood. In retrospect, something that could be 3D modelled and cast out of plastic would be much cheaper and more realistic for a preliminary prototype design, though the surface acrylic panelling was professional and sleek.
  \item Time Management: Many aspects of this project presented significant pressure for our group because of the ambitious nature of our project. We underestimated the amount of time we would spend testing, debugging, and correcting our CR16 processor and other software elements. As a rule of thumb, we should have doubled the time that we initially thought it would take to perform any task.
  \item Foam Buffers for Structural Support: The bottom panels make direct contact with foam buffers in the corners near the assembly screws, and this detracts from the rigidity of the rest of the design. The bottom plate can be pressed up into the rest of the device. To prevent this, the bottom plate should make direct contact with a rigid corner material and fit tightly. This issue would be rectified in a future prototype.
\end{enumerate}
\section{Videos}
We wanted to create a professional video in the form of a product advertisement showing the beauty we captured in the FSS prototype's design. That video is available \href{https://jacobpeterson.net/uofu-ece-3710/ad-video-redirect.html}{here}. Additionally, a demo video showing the basic usage and functional overview of the FSS prototype is available \href{https://jacobpeterson.net/uofu-ece-3710/demo-video-redirect.html}{here}.

\section{About the Team}
There were many tasks involved in creating a functioning synthesizer, and due to this there was much overlap in the division of labor. To list a few:

\begin{itemize}
\item Concept Art
\item Assembly Programming
\item SystemVerilog Programming
\item Test Programs
\item Demo Programs
\item PCB Design
\item PCB Assembly and Reflow
\item Assembler
\item External Housing (Construction)
\item External Housing (Design)
\item Breakout Box Construction
\end{itemize}

Jacob and Nate covered much of the software, namely writing the FSS prototype Verilog modules, the \code{fss.asm} assembly source code, creating demo programs, and implementing the core functionality of the synthesizer. They also worked together to physically assemble, reflow, and test the PCBs, and design the schematic for the breakout box PCB.

Jacob was also responsible for the peripheral interfacing --- writing the I$^2$C procedure in assembly --- and writing the assembler. He worked with Brady to design the Main FSS Board schematic.

Brady conceptualized the idea of a fully synchronized synthesizer and created all of the concept art. He also had a hand in creating test programs, designing the PCB, and designing and constructing the external housing. He and Jacob selected all of the device materials and acquired datasheets in their efforts to design the PCB and physical device housing.

Isabella assisted in creating test programs and constructing the external housing. She also created the synthesizer's breakout box and was responsible for modeling components in SolidWorks before 3D printing.

\section{Conclusion and Future Work}
Overall the final synthesizer came together well and the program reflects most our initial requirements. We were able to design and create a machine that properly updates parameters based on user inputs and can save those into memory to be loaded again when needed later. The final physical product is sleek, fully functional, and is simple to use.

In this version of our synthesizer, we did not have time to work with the audio codec on the FPGA. In a future implementation we hope to get this working so that our synthesizer may play music and have the three dials correspond to audio settings that adjust the sound of the music playing. Beyond this, we would also like to add more inputs, than just the three simple dials. Other commercially available synthesizers have numerous knobs and switches that give users extensive control over the sound the synthesizer makes, and three knobs simply isn't enough to do this.

With these changes, our team could create a high quality synthesizer that has just as much form as function.

\begin{thebibliography}{10}

\bibitem{cite:github_compactrisc16}
  Github,
  Github Repository for ``CompactRISC16'',
  Fall 2021,
  \href{https://github.com/Petersoj/CompactRISC16}{Online}.

\bibitem{cite:github_fssprototype}
  Github,
  Github Repository for ``FSSPrototype'',
  Fall 2021,
  \href{https://github.com/Petersoj/FSSPrototype}{Online}.

\bibitem{cite:rotary_encoders}
  PEC11R Series 12mm Incremental Encoder,
  Bourns,
  PEC11R-4015F-N0024,
  \href{https://www.mouser.com/ProductDetail/Bourns/PEC11R-4015F-N0024?qs=Zq5ylnUbLm5obMMbrbYrpA\%3D\%3D}{Online}.

\bibitem{cite:de1-soc_manual}
  DE1-SoC User Manual,
  TerAsic Technologies,
  April 20216,
  \href{https://www.intel.com/content/dam/www/programmable/us/en/portal/dsn/42/doc-us-dsnbk-42-1004282204-de1-soc-user-manual.pdf}{Online}.

\end{thebibliography}

\clearpage
\setboolean{@twoside}{false}
\includepdf[pages=-, offset=0 0]{"../../../CompactRISC16/docs/Datasheets/CR16 ISA/CR16 ISA.pdf"}

\end{document}

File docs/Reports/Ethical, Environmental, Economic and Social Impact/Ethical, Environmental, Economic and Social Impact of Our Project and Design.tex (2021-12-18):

\documentclass[conference]{IEEEtran}
\usepackage{amsmath,amssymb,amsfonts}
\usepackage{algorithmic}
\usepackage{graphicx}
\usepackage{textcomp}
\usepackage{xcolor}
\usepackage{array}
\usepackage{ragged2e}
\usepackage{multirow} % For multirows in tables
\usepackage{float} % Appending the [H] option forces the placement of a figure in the place it's in the code
\usepackage[numbers]{natbib} % For integration with bibliography commands

\begin{document}

\title{Ethical, Environmental, Economic and Social Impact of Our Project and Design\\[10pt]
\Large{Computer Design Laboratory ECE 3710}\\
\Large{Fall 2021}\\
\Large{The University of Utah}}

\author{\IEEEauthorblockN{Jacob Peterson}
\IEEEauthorblockA{\textit{Computer Engineering 2022}\\
\textit{University of Utah}\\
Salt Lake City, UT}
\and
\IEEEauthorblockN{Brady Hartog}
\IEEEauthorblockA{\textit{Computer Engineering 2022}\\
\textit{University of Utah}\\
Salt Lake City, UT}
\and
\IEEEauthorblockN{Isabella Gilman}
\IEEEauthorblockA{\textit{Computer Engineering 2023}\\
\textit{University of Utah}\\
Salt Lake City, UT}
\and
\IEEEauthorblockN{Nate Hansen}
\IEEEauthorblockA{\textit{Computer Engineering 2023}\\
\textit{University of Utah}\\
Salt Lake City, UT}
}

\maketitle

\section{Ethical and Societal Impact of the FSS Prototype}
The synthesizer our group built would have minimal impact on the environment and on public health and safety, however, we would have to make further considerations to determine if it is sustainable to produce. Newer iterations of the device would be produced based on industry production strategies to eliminate the ``Do-It-Yourself'' elements of the prototype design.

The exterior of our synthesizer was built mainly out of acrylic, and included a real wood veneer covering and a 3D-printed external housing. The interior electrical components were soldered onto a PCB that was interfaced and powered through a USB cable. Continuing to manufacture more of this product would mean use of more plastic and production of more PCBs. The plastic will not break down in nature when the synthesizer is disposed of, and the PCBs will require harsh chemicals for their development. None of these materials are regulated and do not pose a threat to manufacturers or consumers. We believe the greatest environmental impact of our design would be shipping it by plane from its production hub, which would likely be southeast Asia. Since this is only a method of transportation for expedited shipping, and travel by sea freight is much more $CO_2$ efficient, the ethical responsibility lies with the consumer to chose a shipping method that aligns with their values.

The current chip shortage may impact the production of these synthesizers on a larger scale. Our prototype's main program ran on our custom 16-bit RISC CPU which was compiled to run on an FPGA, but a more finalized version would use various fabricated chips, such as microcontrollers and other ASICs, instead of an FPGA. The chip shortage may make this difficult because manufacturing custom CPUs would be more costly and would likely be backlogged.

Although all other materials are readily available, their cost indicates that our device may not be sustainable to produce according to its prototype design. In total, the FSS Prototype costs approximately \$500 in material, and automated assembly at a larger scale would also carry a cost. Although some components and materials in the Bill of Materials (BOM) were not used, the final product was quite expensive and had a lengthy assembly process. However, given what we have learned about the assembly process, we believe we could enhance the BOM for future models and devise a more strategic, sustainable device composition that could be produced at a large scale.

\end{document}

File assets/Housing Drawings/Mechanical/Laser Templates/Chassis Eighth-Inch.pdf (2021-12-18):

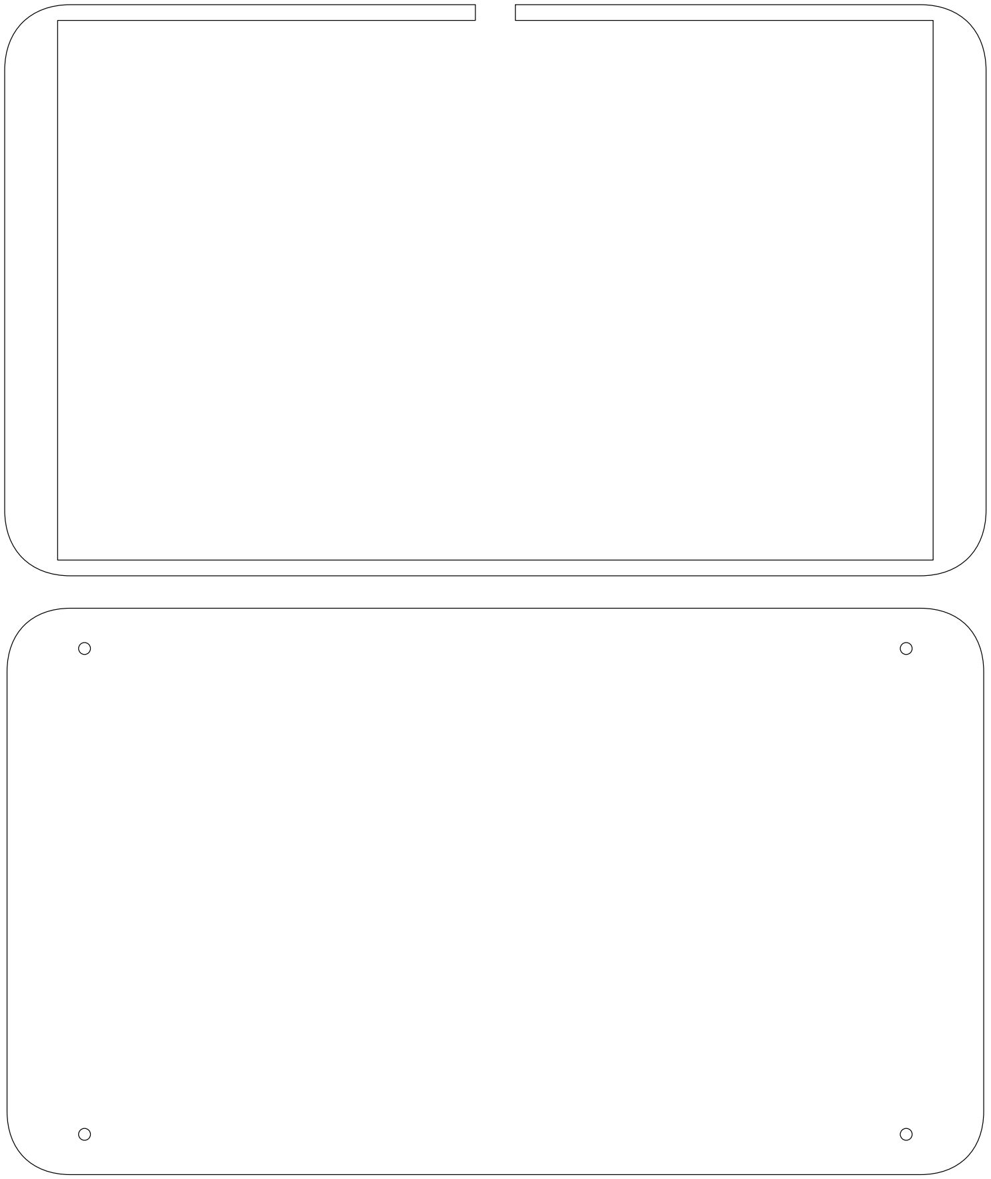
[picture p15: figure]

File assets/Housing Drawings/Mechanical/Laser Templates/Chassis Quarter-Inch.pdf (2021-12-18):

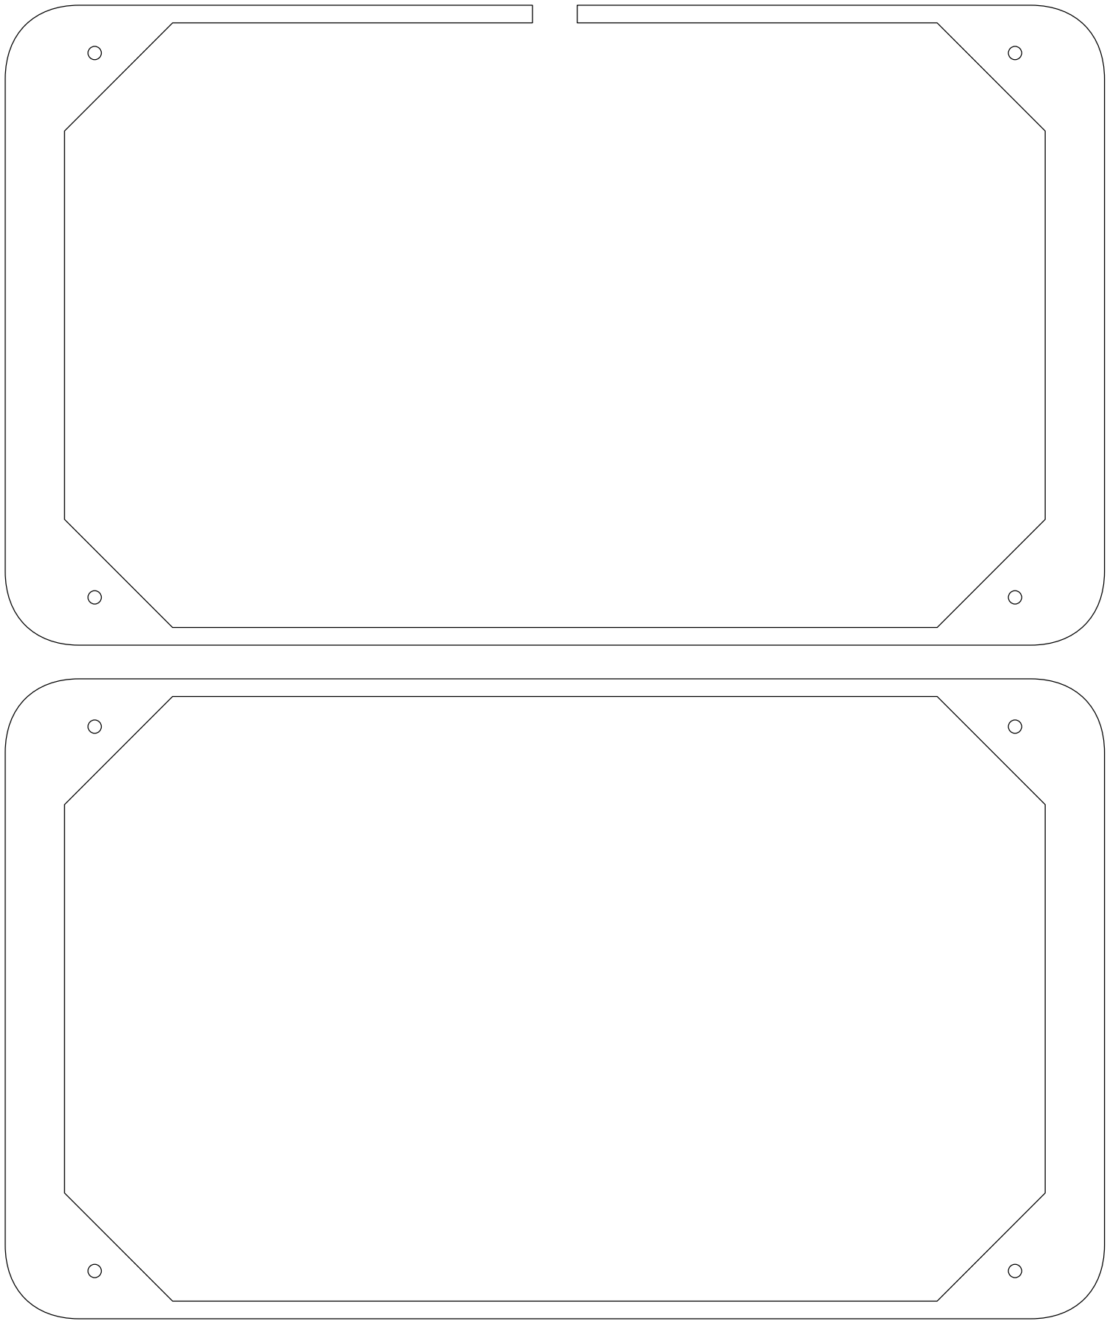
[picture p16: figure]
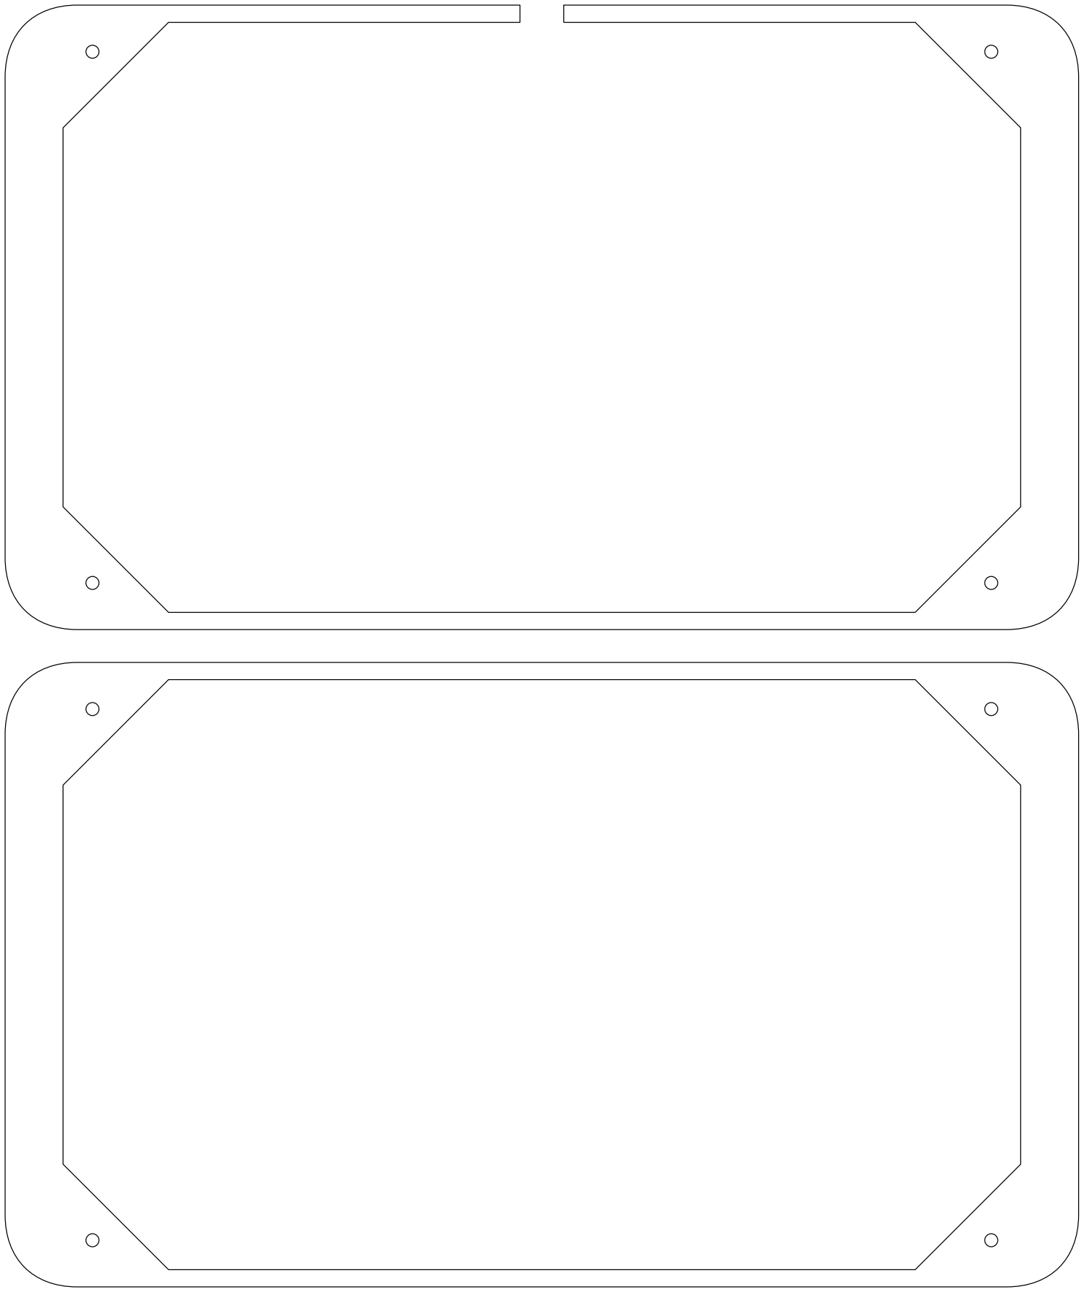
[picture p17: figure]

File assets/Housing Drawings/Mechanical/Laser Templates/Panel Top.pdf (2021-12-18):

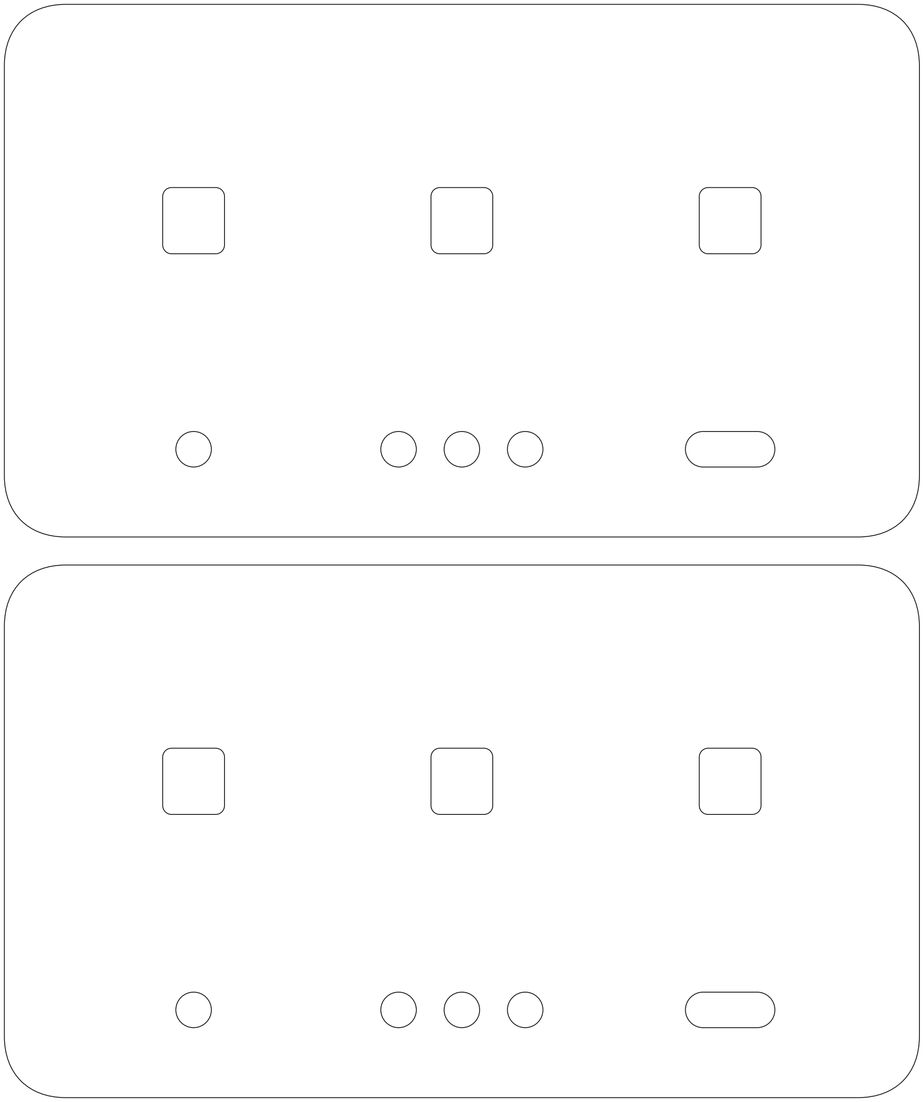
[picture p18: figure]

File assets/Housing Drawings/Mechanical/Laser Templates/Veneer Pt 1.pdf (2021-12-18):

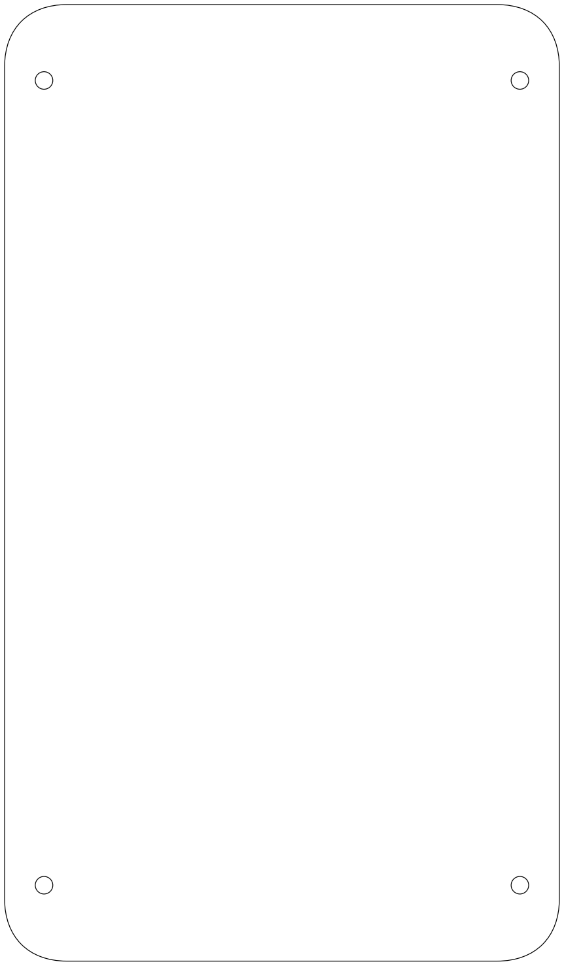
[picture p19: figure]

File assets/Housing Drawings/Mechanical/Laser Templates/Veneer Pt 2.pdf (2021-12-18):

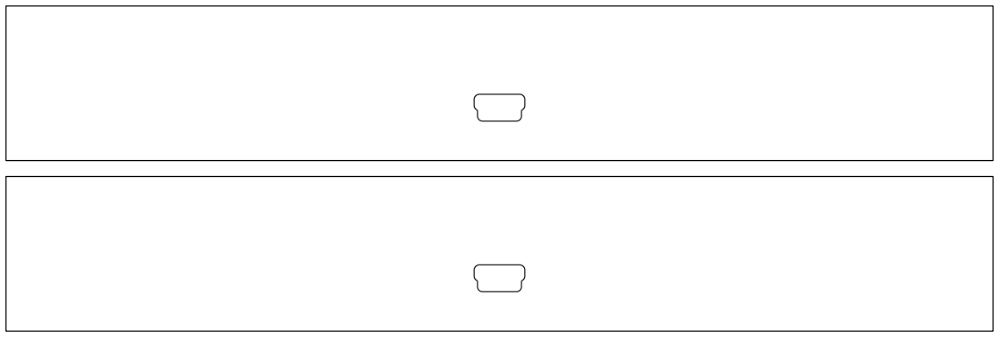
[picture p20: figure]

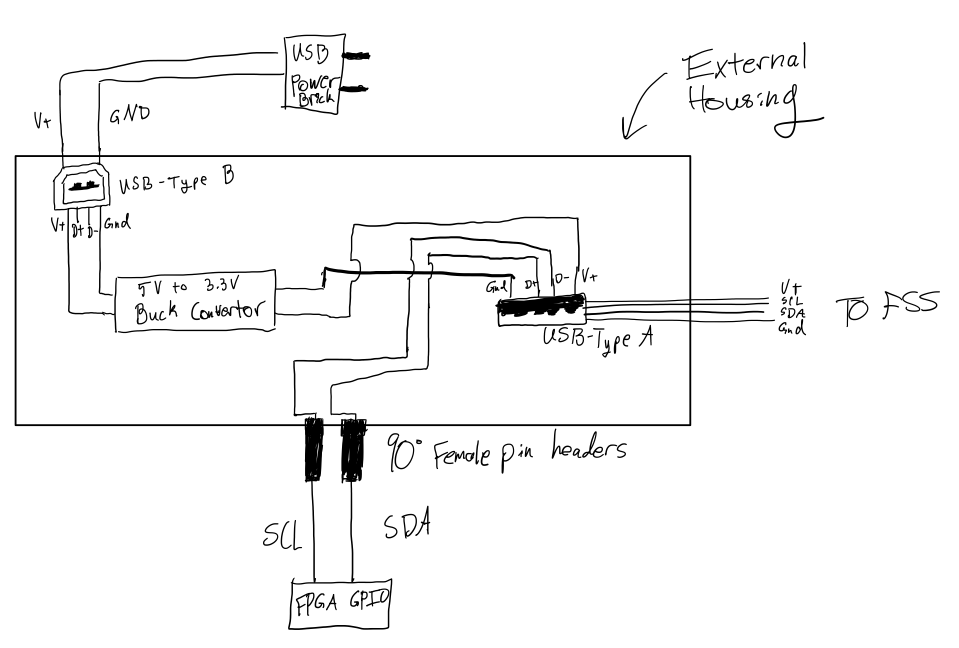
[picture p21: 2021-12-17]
assets/Housing Drawings/Concept/Rough Schematic for External Breakout PCB.png

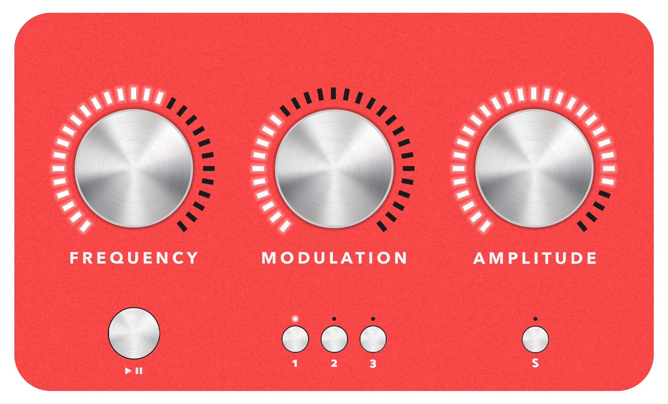
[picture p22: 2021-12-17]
assets/Housing Drawings/Concept/Top Panel Artwork Idea.png

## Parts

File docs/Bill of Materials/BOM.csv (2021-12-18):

Description | Mfg. Part Number | Listing | Schematic Reference | Quantity | Total Price ($)
SMD LED, amber, package 1206 | HSMA-C350 | Digi-Key | Main: LED1 - LED62 | 139 | 48.29
LED driver, 16-bit shift-register with latching | STP16CPC05MTR | Digi-Key | Main: U1 - U4 | 10 | 17.76
Push button, flat, tactile, SPST, normally open | TS05-66-50-BK-260-SMT-67 | Digi-Key | Main: U5 - U9 | 13 | 4.56
Rotary encoder, mechanical, 15mm D-shaft, 24 PPR, no detents | PEC11R-4015F-N0024 | Mouser | Main: SW1 - SW3 | 8 | 11.52
I/O port expander, 8-bit, I2C protocol | PCF8574ADWR | Mouser | Main: U10, U11 | 6 | 11.7
USB Mini Type B connector, female, 1.5A | GMSB0522102Y7EU | Mouser | Main: USB1 | 3 | 4.2
SMD resistor, 1/4W 1Kohms 1% | — | Mouser | Main: R22 - R25 | 10 | 1.62
SMD resistor, 1/4W 2Kohms 1% | — | Mouser | Main: R26, R27 | 6 | 1.14
SMD resistor, 1/4W 10Kohms 1% | — | Mouser | Main: R1 - R6, R11, R12, R15 - R21 | 35 | 5.25
SMD resistor, 1/4W 330ohms 1% | — | Mouser | Main: R28, R29 | 6 | 1.14
SMD ceramic capacitor, 10V 0.1uF 0805 5% | — | Mouser | Main: C1 | 4 | 2.52
Various SMD resistors, 1/8W 0-10MOhm 1% | — | Amazon | — | 1 | 8.18
USB Type A to Mini B braided cable, USB 2.0, black | — | Amazon | — | 2 | 15.06
SPST rocker switch | 1941.1103 | Mouser | Breakout: SW1 | 3 | 4.41
USB Type A connector, female, 1.5A | USB1046-GF-0190-L-B-A | Mouser | Breakout: USB-A | 3 | 2.25
USB Type B connector, female, 1.5A | 61729-0010BLF | Mouser | Breakout: USB-B | 3 | 3.51
Pin header, 1x2, right angle 2.54mm | 22-28-9023 | Mouser | Breakout: I2C | 4 | 0.96
DC-DC buck converter, 3A current rating | LM2596 | Amazon | Breakout: IN+, IN-, OUT+, OUT- | 5 | 9.69
Digi-Key shipping, tariff, sales tax | — | — | — | — | 16.79
Mouser shipping and sales tax | — | — | — | — | 11.88
JLCPCB PCBs and shipping | — | — | — | — | 57.38
1/8" Acrylic sheet, opaque black, 12" x 24" | 2025 Black | Delvie's Plastics | — | 1 | 11.5
1/8" Acrylic sheet, transparent bronze, 12" x 12" | 2370 Bronze | Delvie's Plastics | — | 1 | 7.25
1/8" Acrylic sheet, frosted clear, 12" x 12" | — | Delvie's Plastics | — | 1 | 6
1/8" Acrylic sheet, transparent clear, 12" x 12" | — | Delvie's Plastics | — | 1 | 5.25
1/4" Acrylic sheet, transparent clear, 12" x 24" | — | Delvie's Plastics | — | 1 | 15.75
Wood veneer, mahogany | — | Woodcraft | — | 1 | 12.83
Wood veneer, walnut | — | Woodcraft | — | 1 | 13.9
Cyanoacrylate super glue liquid, 5 grams | — | Ace Hardware | — | 2 | 9.82
Water-based wood finish, semi-gloss, 0.5 pt | — | Ace Hardware | — | 1 | 13.9
Adhesive foam tape | — | Amazon | — | 1 | 12.92
Machine screw caps, brushed aluminum | — | Amazon | — | 8 | 12
Machine screws, counter-sink, #6-32, 1/2" length | — | — | — | 8 | —
Machine screws, round head, #6-32, 1.5" length | — | — | — | 4 | —
5V DC wall adapter | — | — | — | 2 | —
USB Type A to Type B cable | — | — | — | 2 | —
PLA 3D printing filament, black | — | — | — | — | —
Terasic DE1-SoC board, Cyclone V | Cyclone V: 5CSEMA5F31C6 | — | — | 2 | —
 |  |  |  |  | Grand Total
 |  |  |  |  | 360.93
Estimate for two (2) fully assembled FSS prototypes.

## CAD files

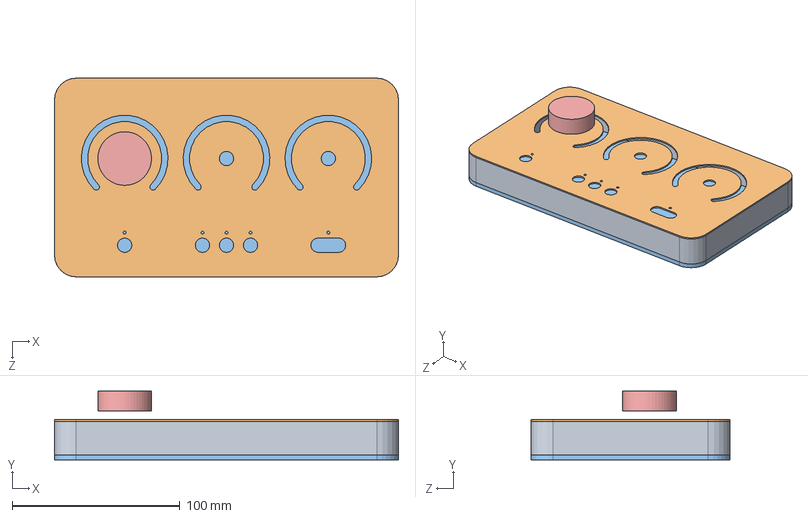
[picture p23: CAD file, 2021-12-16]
assets/Housing Drawings/Mechanical/SolidWorks/synth_assembly.SLDASM
205.4 x 41.2 x 118.6 mm
Housing
Top_Panel
PCB_Outline
Knob

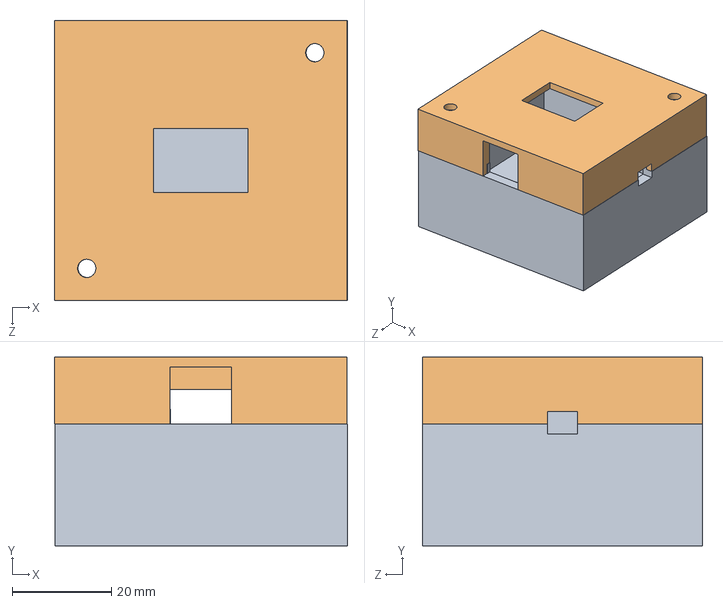
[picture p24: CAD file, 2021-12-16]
assets/Housing Drawings/Mechanical/SolidWorks/external_housing_assembly.SLDASM
59.1 x 38.1 x 56.5 mm
external_housing_bottom
External_Housing_Top

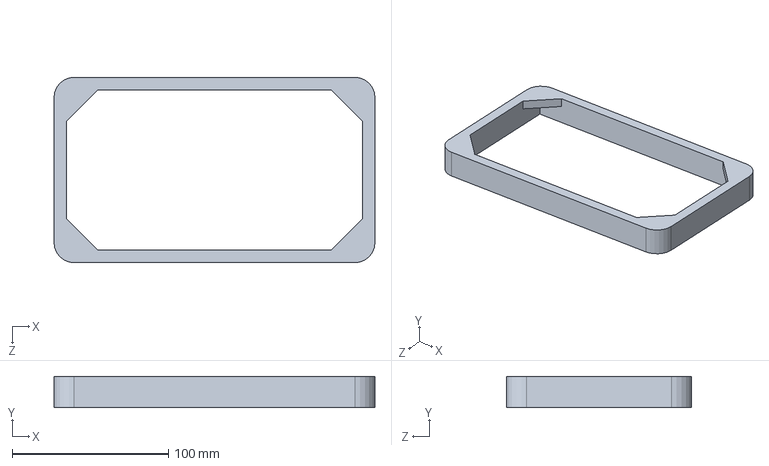
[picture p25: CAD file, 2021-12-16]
assets/Housing Drawings/Mechanical/SolidWorks/housing.SLDPRT
205.4 x 20.0 x 118.6 mm

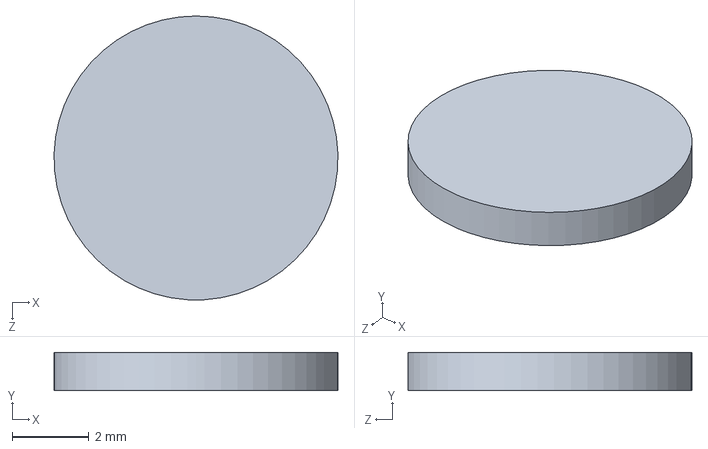
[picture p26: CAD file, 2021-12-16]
assets/Housing Drawings/Mechanical/SolidWorks/button_spacer.SLDPRT
7.40 x 1.00 x 7.40 mm

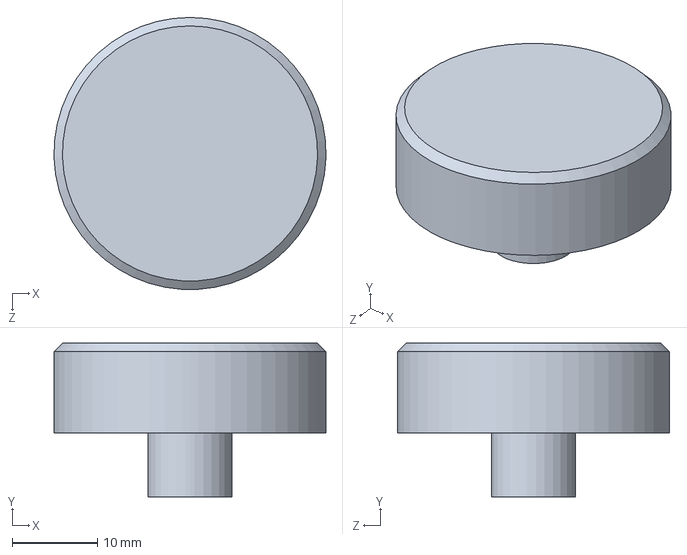
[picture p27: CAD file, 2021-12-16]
assets/Housing Drawings/Mechanical/SolidWorks/dowl_insert.SLDPRT
32.0 x 18.1 x 32.0 mm

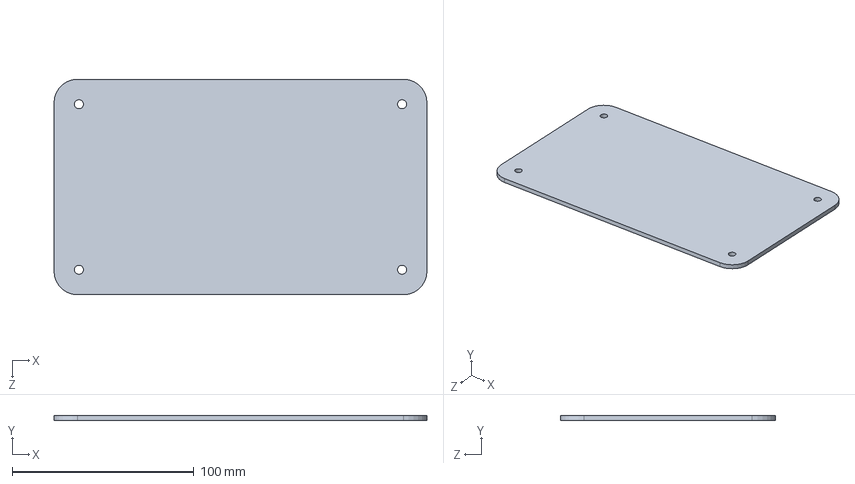
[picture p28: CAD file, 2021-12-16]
assets/Housing Drawings/Mechanical/SolidWorks/bottom_panel.SLDPRT
205.4 x 3.00 x 118.6 mm

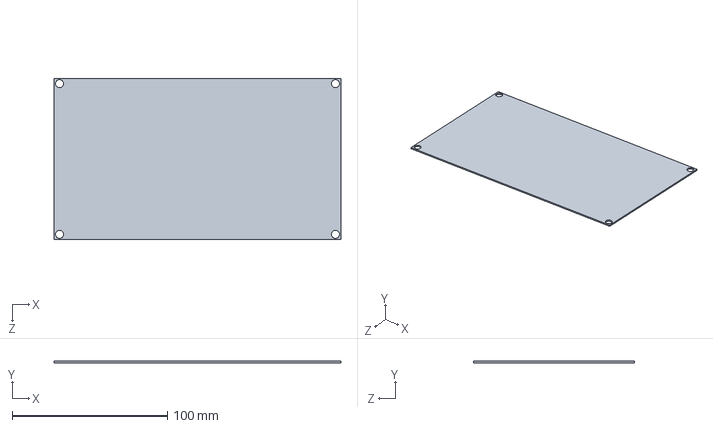
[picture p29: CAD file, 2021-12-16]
assets/Housing Drawings/Mechanical/SolidWorks/pcb_outline.SLDPRT
185.0 x 1.00 x 104.0 mm

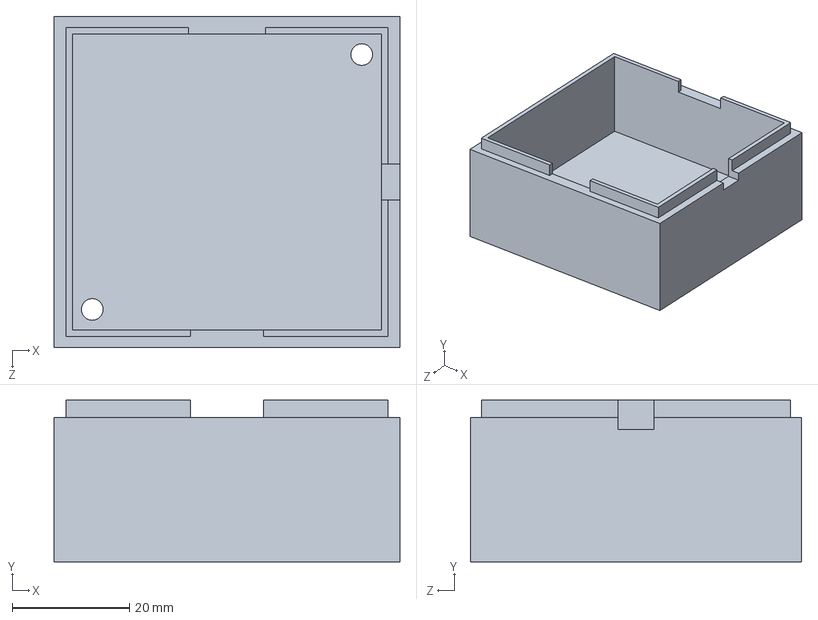
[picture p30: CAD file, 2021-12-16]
assets/Housing Drawings/Mechanical/SolidWorks/external_housing_bottom.SLDPRT
59.0 x 27.6 x 56.5 mm

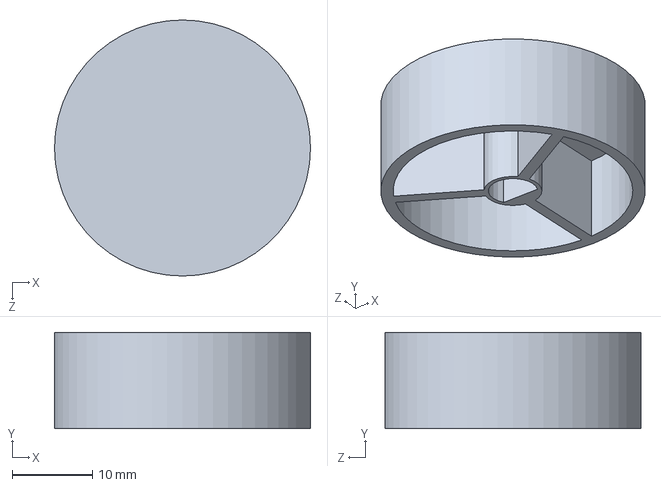
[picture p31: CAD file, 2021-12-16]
assets/Housing Drawings/Mechanical/SolidWorks/knob.SLDPRT
32.0 x 12.0 x 32.0 mm

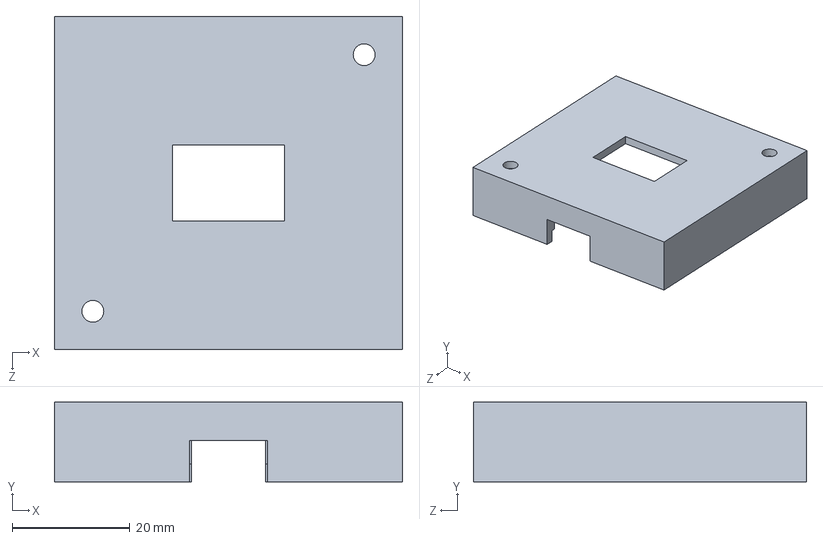
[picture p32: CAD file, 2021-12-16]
assets/Housing Drawings/Mechanical/SolidWorks/external_housing_top.SLDPRT
59.0 x 13.5 x 56.5 mm

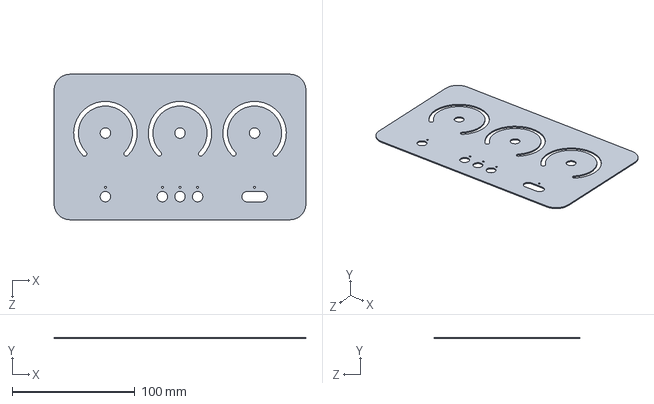
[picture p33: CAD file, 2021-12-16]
assets/Housing Drawings/Mechanical/SolidWorks/top_panel.SLDPRT
205.4 x 1.00 x 118.6 mm

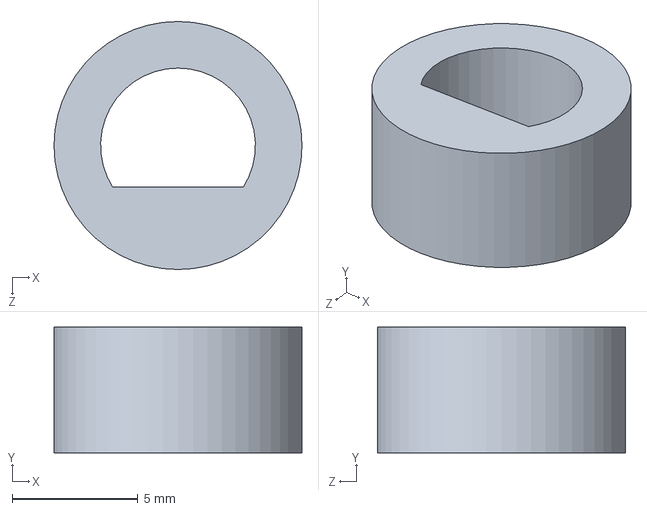
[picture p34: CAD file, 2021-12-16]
assets/Housing Drawings/Mechanical/SolidWorks/extender.SLDPRT
9.85 x 5.00 x 9.85 mm

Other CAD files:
assets/Housing Drawings/Mechanical/SolidWorks/dowl_insert.SLDDRW
assets/Housing Drawings/Mechanical/SolidWorks/housing.SLDDRW

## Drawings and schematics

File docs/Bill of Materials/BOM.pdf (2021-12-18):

## Expense Sheet - BOM

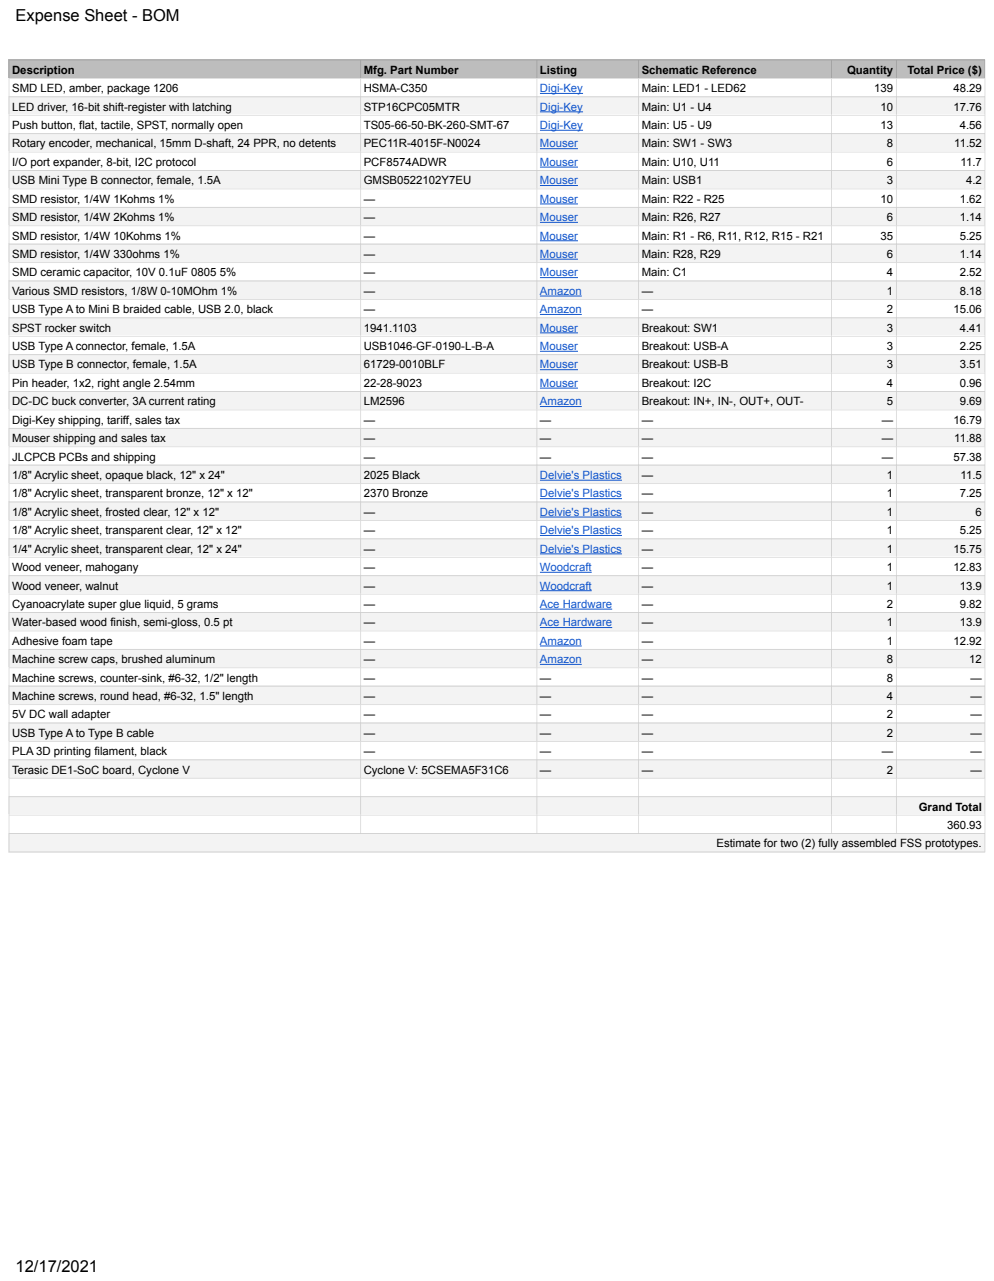
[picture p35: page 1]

Estimate for two (2) fully assembled FSS prototypes.

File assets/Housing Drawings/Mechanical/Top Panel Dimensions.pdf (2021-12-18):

# TO SCALE

# University of Utah

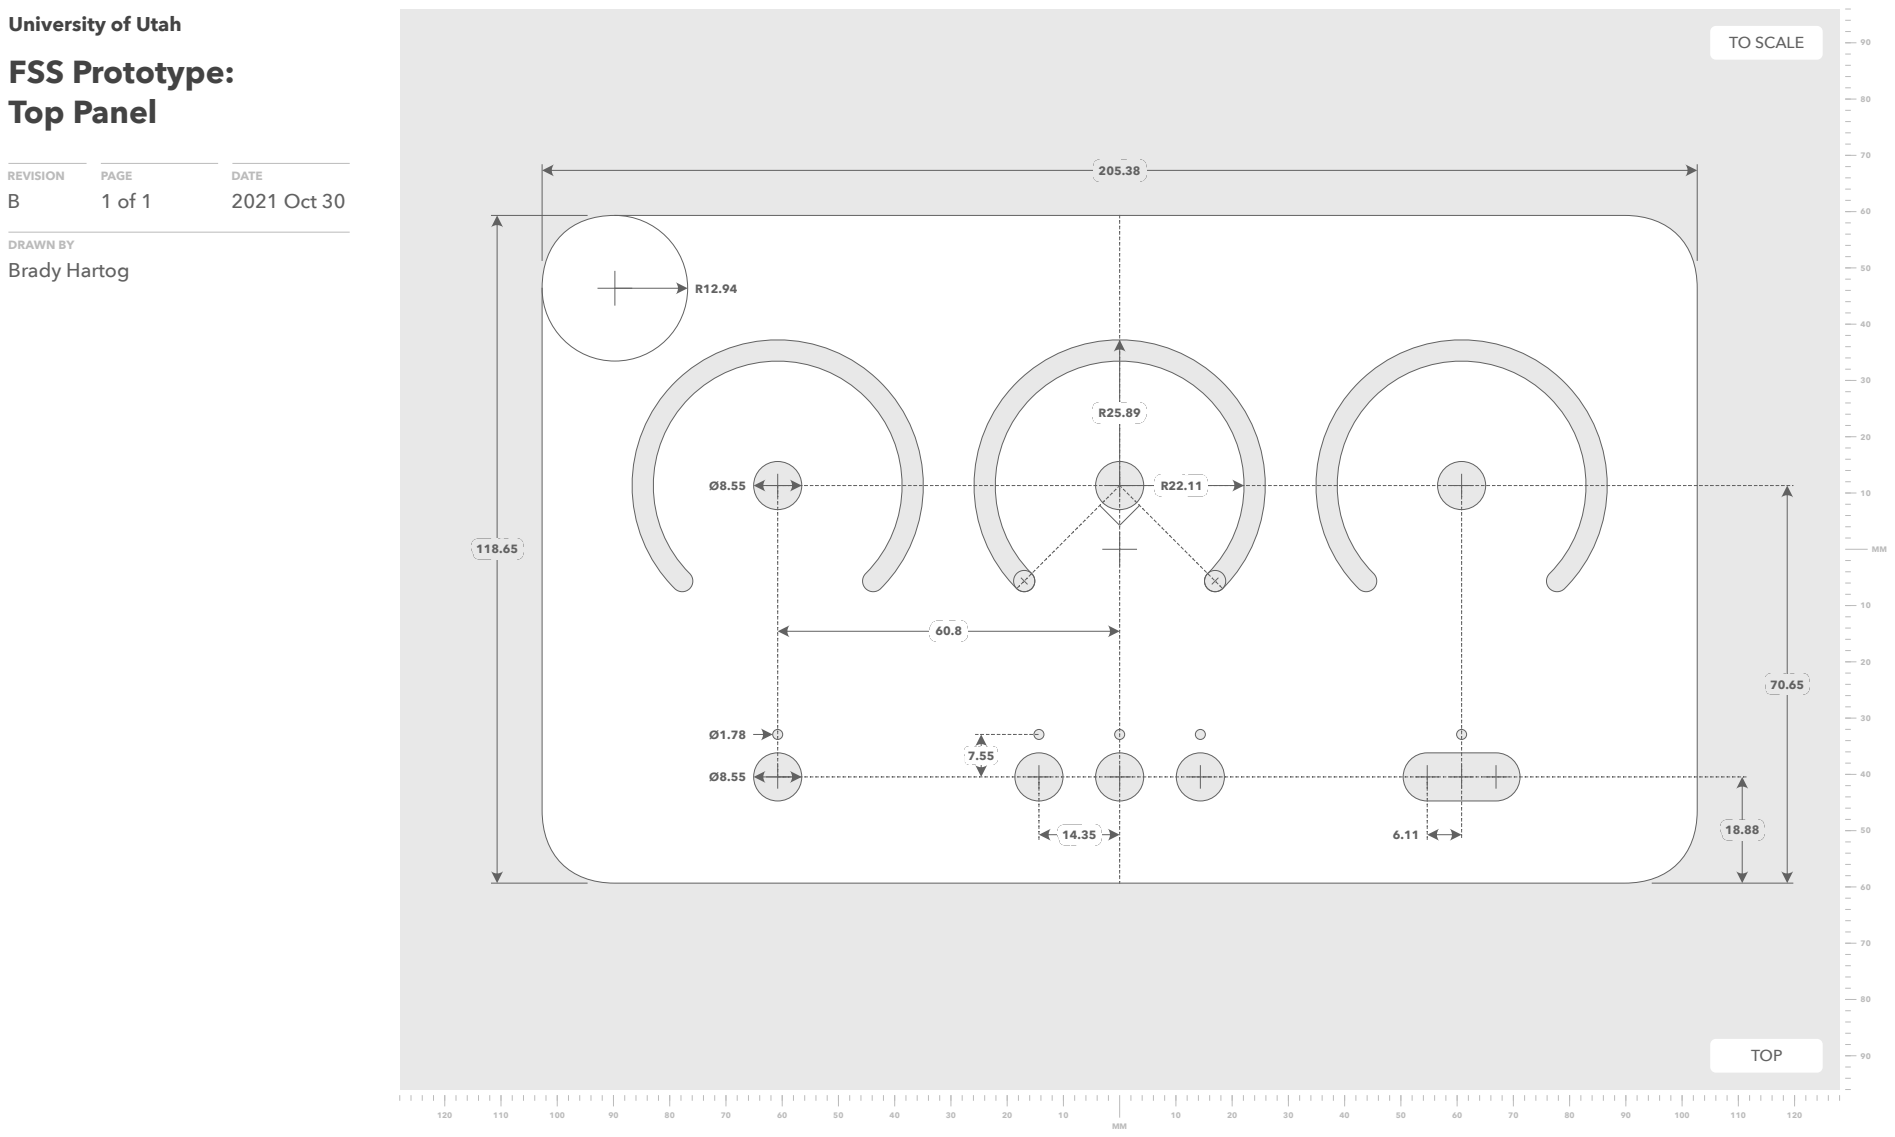
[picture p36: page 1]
TOP; FSS Prototype: Top Panel; REVISION B; DRAWN BY Brady Hartog; PAGE 1 of 1; DATE 2021 Oct 30

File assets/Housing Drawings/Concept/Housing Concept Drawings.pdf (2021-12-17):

# TO SCALE

# University of Utah

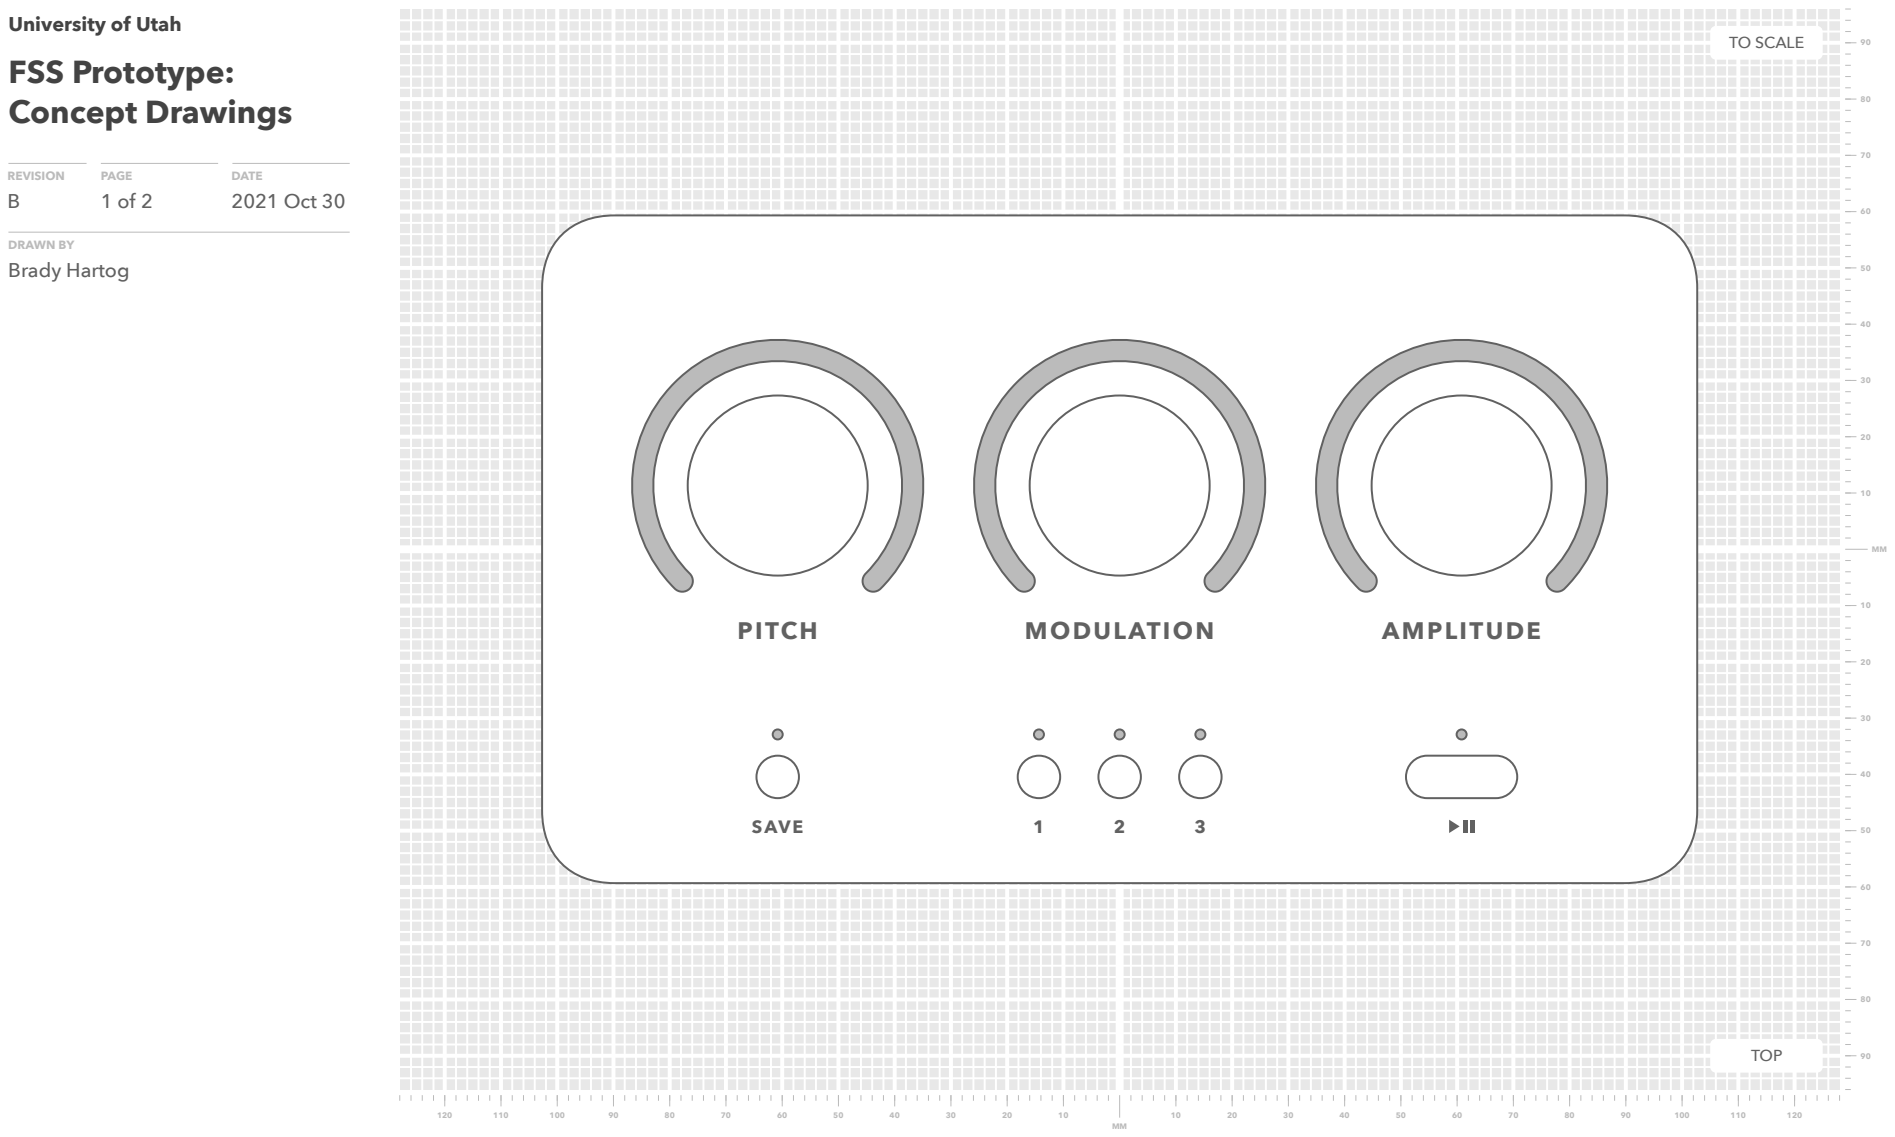
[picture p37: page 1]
TOP; FSS Prototype: Concept Drawings; REVISION B; DRAWN BY Brady Hartog; PAGE 1 of 2; DATE 2021 Oct 30; P ITCH; SAVE; MODULAT ION; AMPL ITUDE

# TO SCALE

# University of Utah

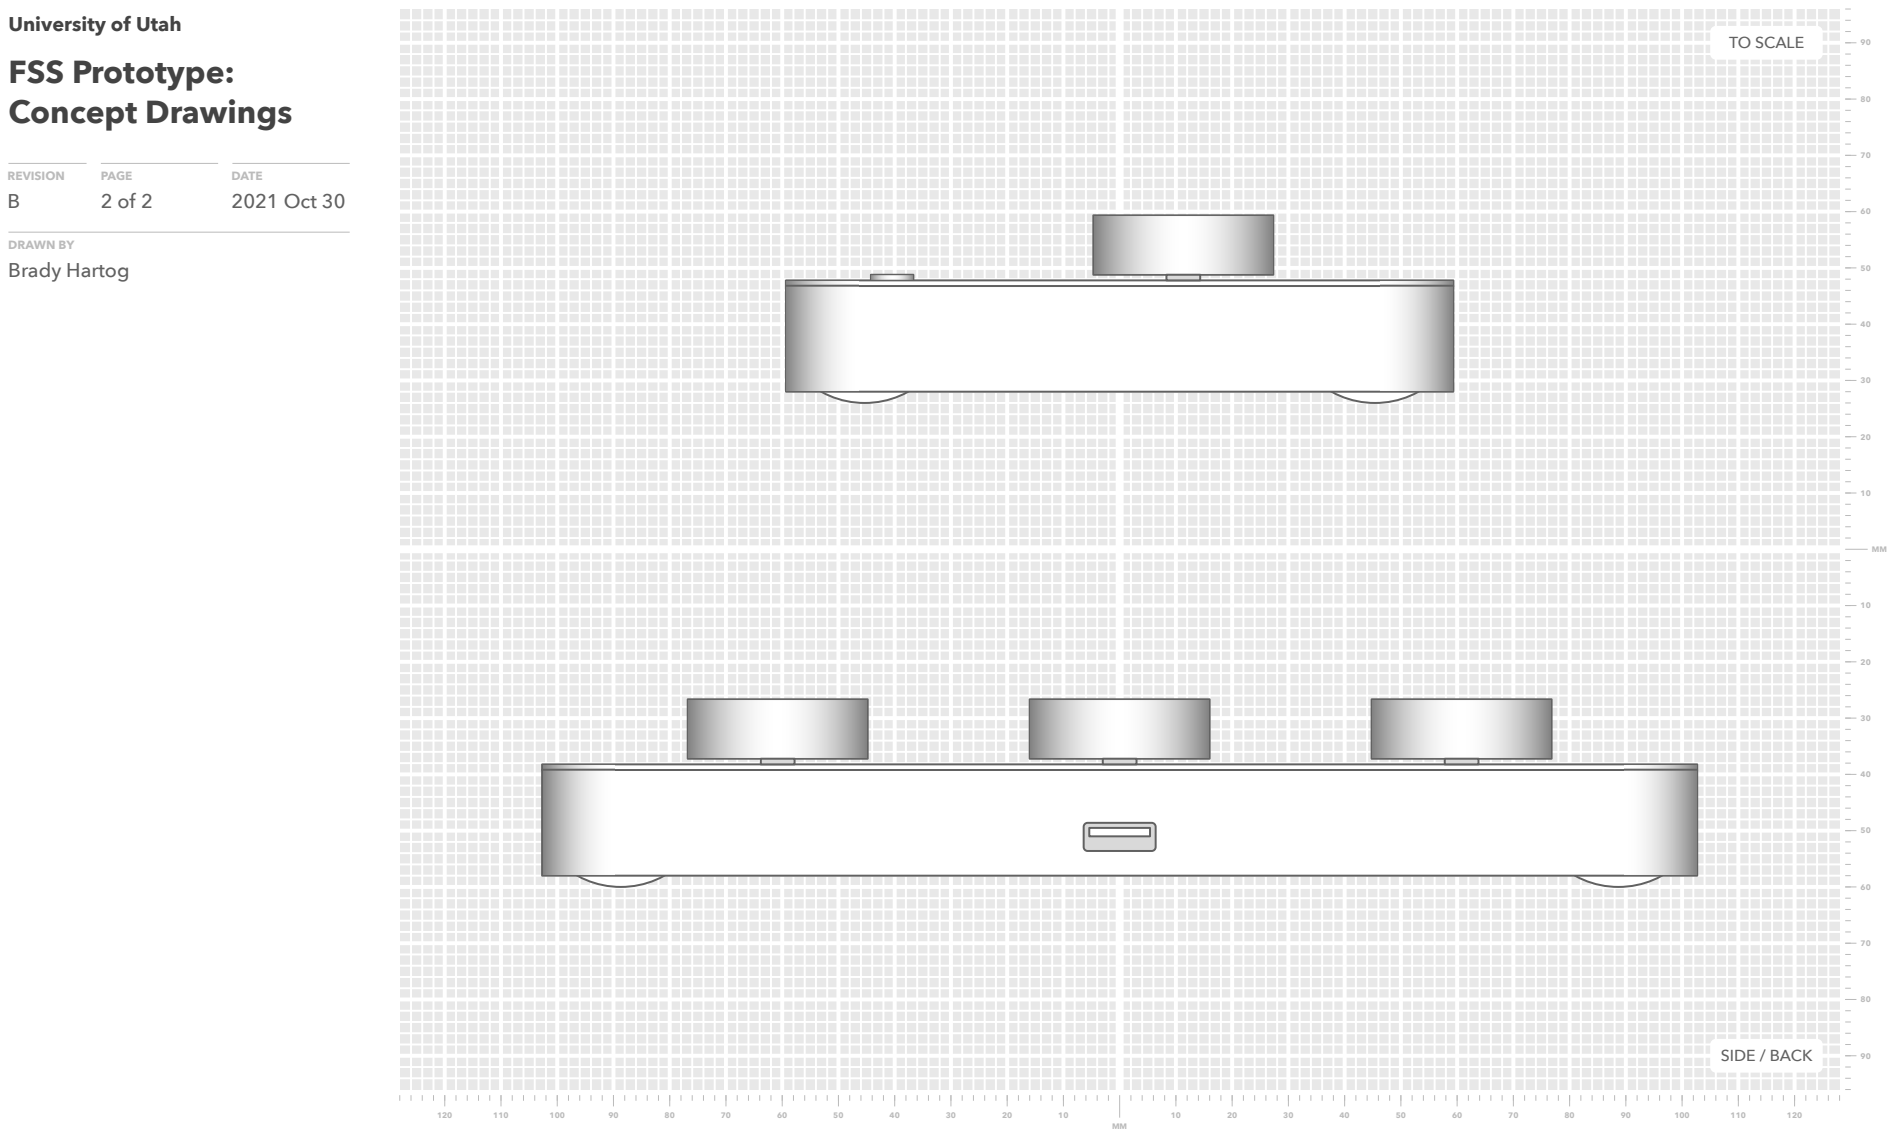
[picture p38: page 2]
SIDE / BACK; FSS Prototype: Concept Drawings; REVISION B; DRAWN BY Brady Hartog; PAGE 2 of 2; DATE 2021 Oct 30

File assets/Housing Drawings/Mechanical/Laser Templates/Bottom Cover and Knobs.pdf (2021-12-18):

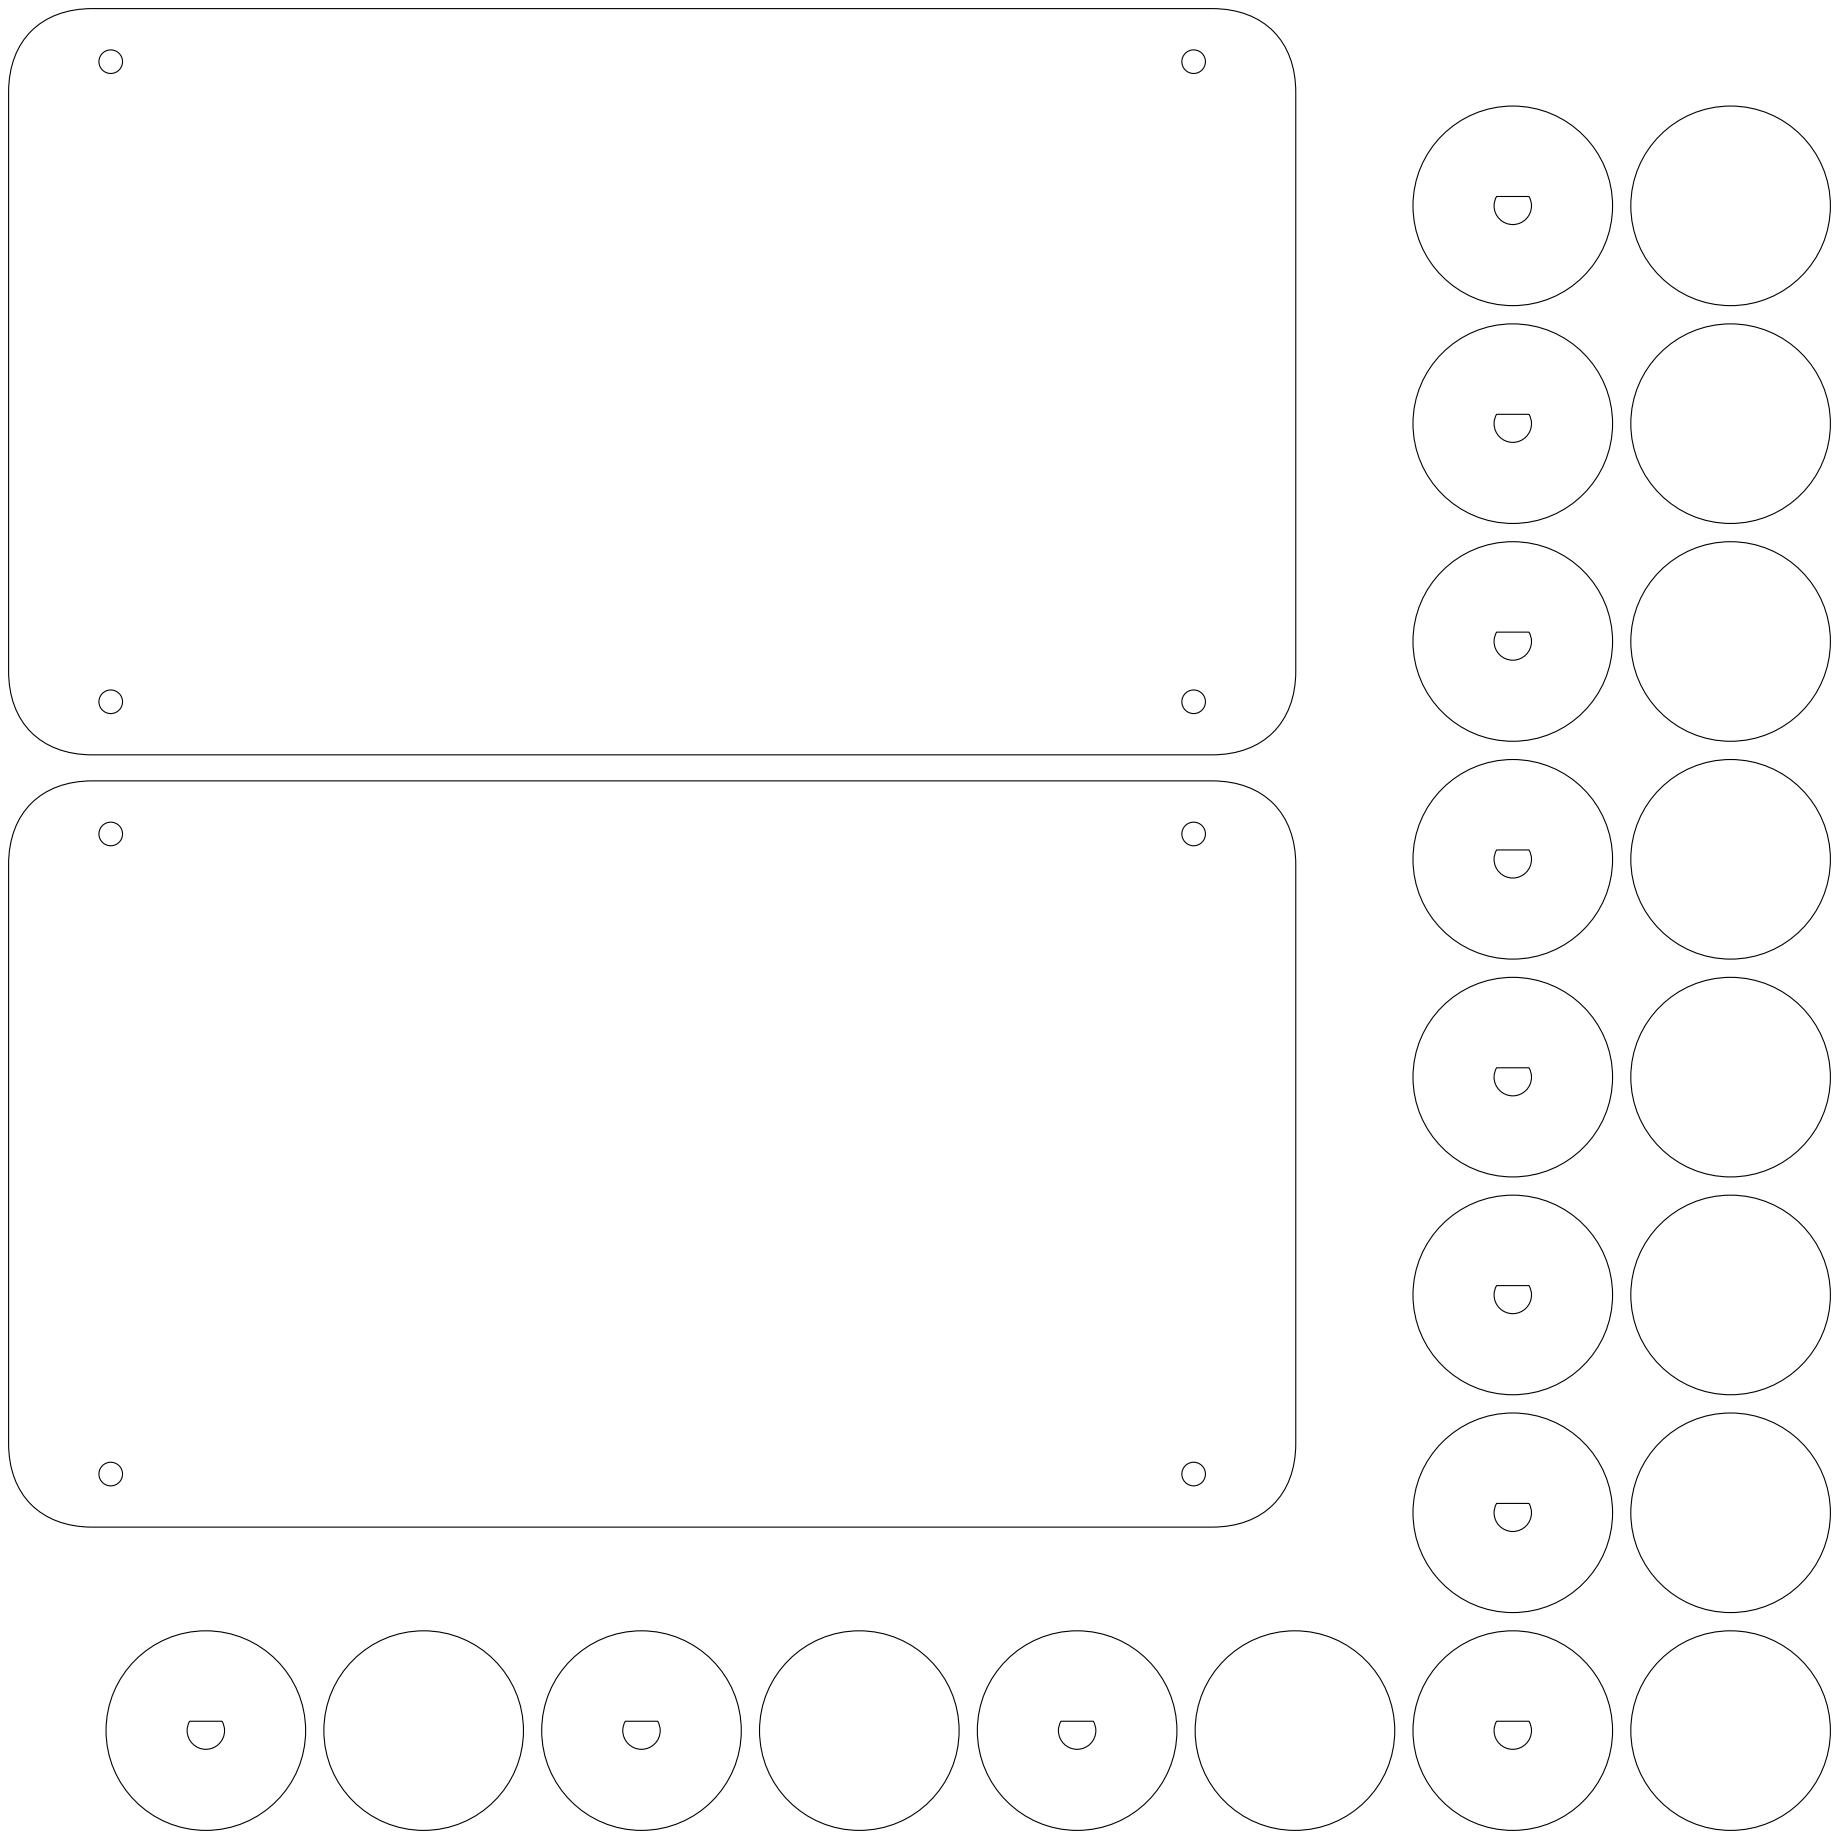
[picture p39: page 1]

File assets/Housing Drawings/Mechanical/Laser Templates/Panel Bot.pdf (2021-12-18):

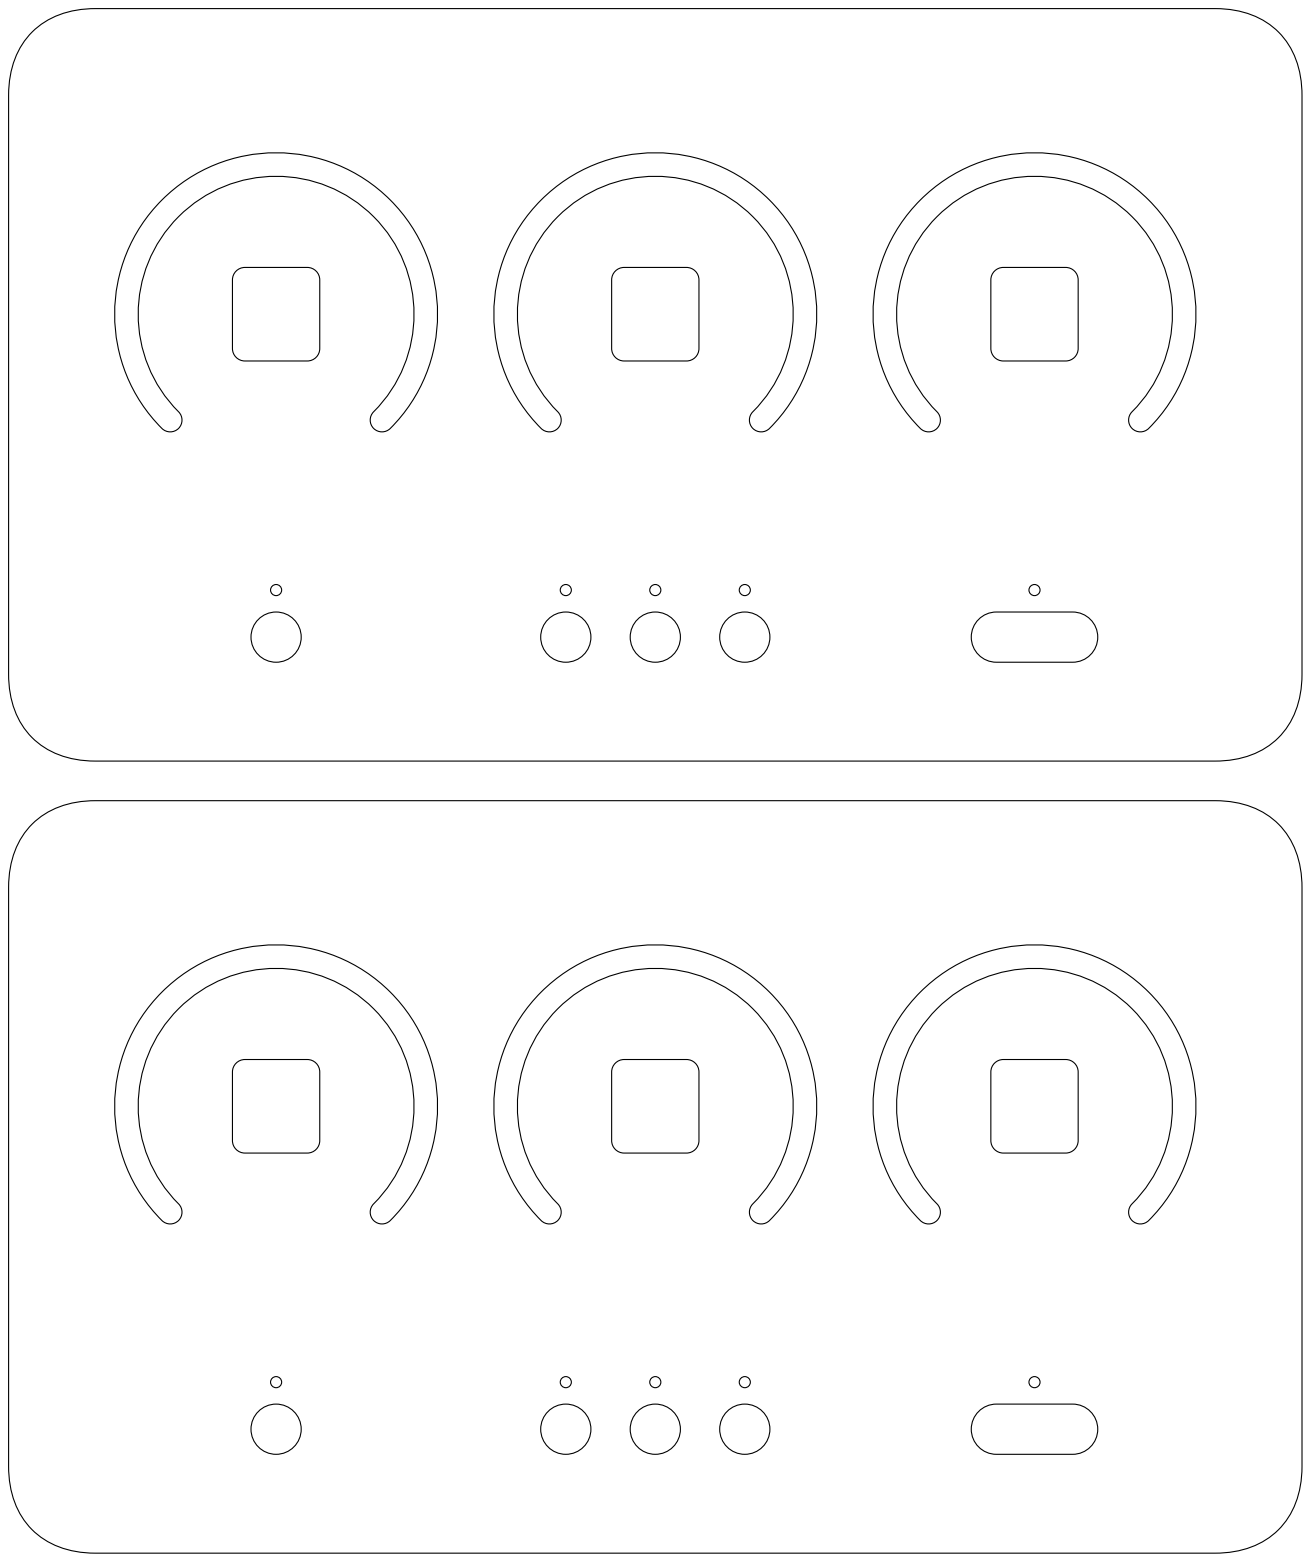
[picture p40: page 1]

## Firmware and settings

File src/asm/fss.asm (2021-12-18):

#
# University of Utah, Computer Design Laboratory ECE 3710, FSSPrototype
#
# Create Date: 12/04/2021
# Name: fss
# Description: This is the main program for the FSS prototype written in our custom assembly code,
# compiled with our custom assembler, and running our custom CompactRISC16 processor. This code
# will load onto an FPGA to drive the I2C protocol communication with the device hardware via GPIO
# pins. Data is read from various buttons and rotary encoders on the FSS, and processed data is
# written to a series of SMD LEDs that are driven with daisy-chained shift register LED drivers.
# Authors: Nate Hansen, Jacob Peterson, Brady Hartog, Isabella Gilman
#

#
# BEGIN: Program init and main function
#

`define STACK_PTR_LOWER 0xFF
`define STACK_PTR_UPPER 0x0F

##
# The program initialization routine.
#
# @return void
##
.init
    # Initialize stack pointer
    MOVIL   rsp STACK_PTR_LOWER
    MOVIU   rsp STACK_PTR_UPPER

##
# The main function.
#
# @return void
##
.main
    CALL    .animation_sequence_startup
    JUC     .run

#
# END: Program init and main function
#








#
# BEGIN: Program run functions
#

#
# BEGIN: Static memory definitions
#

# The following is an array of length 8 with the following index mapping:
# | Index | Description                                       |
# | 0     | 1st ring display value (must be 0 - 19, 0 is off) |
# | 1     | 2nd ring display value (must be 0 - 19, 0 is off) |
# | 2     | 3rd ring display value (must be 0 - 19, 0 is off) |
# | 3     | Save indicator value (must be 0 or 1)             |
# | 4     | Program1 indicator value (must be 0 or 1)         |
# | 5     | Program2 indicator value (must be 0 or 1)         |
# | 6     | Program3 indicator value (must be 0 or 1)         |
# | 7     | Play/Pause indicator value (must be 0 or 1)       |
.display_values_active
0
0
0
0
0
0
0
0

# The following are arrays of length 3 with the following index mapping:
# | Index | Description                                       |
# | 0     | 1st ring display value (must be 0 - 19, 0 is off) |
# | 1     | 2nd ring display value (must be 0 - 19, 0 is off) |
# | 2     | 3rd ring display value (must be 0 - 19, 0 is off) |
.display_values_program_1
9
9
9
.display_values_program_2
2
17
8
.display_values_program_3
11
15
19

# Define a memory location for the current "Play/Pause" button sequence index
.button_playpause_pressed_sequence_index
0x0001

# Define a memory location for the '.rotary_encoder_decode' function for the rotary encoders
.rotary_encoder_1
0x0000
.rotary_encoder_2
0x0000
.rotary_encoder_3
0x0000

#
# END: Static memory definitions
#

##
# Runs the FSS prototype program. This function runs indefinitely.
#
# @return void
##
.run
    # Copy program 1 display values into active values
    MOV     r11 .display_values_program_1
    MOV     r12 .display_values_active
    MOVIL   r13 3
    MOVIU   r13 0x00
    CALL    .array_copy

    # Indicate program 1 is active
    MOVIL   r11 0b0000_0010
    MOVIU   r11 0x00
    CALL    .set_display_values_active_indicators

    # Display active values
    MOV     r11 .display_values_active
    CALL    .set_ring_display_and_indicator_values

    .run:loop

    CALL    .handle_buttons
    CALL    .handle_rotary_encoders

    JUC     .run:loop

    # Handle button press events

##
# Polls and processes the buttons on the FSS prototype.
#
# @return void
##
.handle_buttons
    CALL    .button_get_values

    PUSH    r10 # Push caller-saved registers
    # Check if "Save" button is pressed
    MOV     r11 r10
    CALL    .button_is_save_pressed
    CMPI    r10 1
    JNE     .handle_buttons:skip_button_save_pressed
    CALL    .button_save_pressed
    .handle_buttons:skip_button_save_pressed
    POP     r10 # Pop caller-saved registers

    PUSH    r10 # Push caller-saved registers
    # Check if "Program" button is pressed
    MOV     r11 r10
    CALL    .button_is_program_pressed
    CMPI    r10 0
    JEQ     .handle_buttons:skip_button_program_pressed
    MOV     r11 r10
    CALL    .button_program_pressed
    .handle_buttons:skip_button_program_pressed
    POP     r10 # Pop caller-saved registers

    PUSH    r10 # Push caller-saved registers
    # Check if "Play/Pause" button is pressed
    MOV     r11 r10
    CALL    .button_is_playpause_pressed
    CMPI    r10 1
    JNE     .handle_buttons:button_playpause_pressed
    CALL    .button_playpause_pressed
    .handle_buttons:button_playpause_pressed
    POP     r10 # Pop caller-saved registers

    RET

##
# Polls and processes the rotary encoders on the FSS prototype.
#
# @return void
##
.handle_rotary_encoders
    CALL    .rotary_encoder_get_values

    # Push caller-saved registers
    PUSH    r10
    # Process rotary encoder 1
    MOV     r11 .rotary_encoder_1
    MOV     r12 r10
    ANDI    r12 0b0000_00011
    MOV     r13 .display_values_active
    CALL    .process_rotary_encoder
    # Pop caller-saved registers
    POP     r10

    # Push caller-saved registers
    PUSH    r10
    # Process rotary encoder 2
    MOV     r11 .rotary_encoder_2
    MOV     r12 r10
    RSHI    r12 2
    ANDI    r12 0b0000_00011
    MOV     r13 .display_values_active
    ADDI    r13 1
    CALL    .process_rotary_encoder
    # Pop caller-saved registers
    POP     r10

    # Push caller-saved registers
    PUSH    r10
    # Process rotary encoder 3
    MOV     r11 .rotary_encoder_3
    MOV     r12 r10
    RSHI    r12 4
    ANDI    r12 0b0000_00011
    MOV     r13 .display_values_active
    ADDI    r13 2
    CALL    .process_rotary_encoder
    # Pop caller-saved registers
    POP     r10

    RET
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

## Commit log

2021-12-04 Finished open-drain config for I2C bus
2021-12-04 updated header comments on i2c and open_drain. WIP on fss_top and ext_mem
2021-12-05 Finish ext_mem and others, Add test_microsecond_counter,update README
    [5CSEMA5F31C6N_fss_top.csv]
2021-12-06 README formatting, fix errors in WIP fss.asm, add compiled fss.dat
    [fss.asm]
2021-12-07 Implement I2C functions in fss.asm
2021-12-08 animation_sequence_startup, idle_animation_sequence, button interfacing
2021-12-09 Fix .rotary_encoder_decode, add .rotary_encoder_get_values
    [fss.asm]
2021-12-16 Add SolidWorks drawings, parts, and assembly to assets
    [bottom_panel.SLDPRT, button_spacer.SLDPRT, dowl_insert.SLDDRW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]
2021-12-17 Add concept drawings from Google Drive, organize assets/
    [bottom_panel.SLDPRT, button_spacer.SLDPRT, dowl_insert.SLDDRW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]
2021-12-17 Add Breakout and Main schematic and PCB PDFs, rename directory
    [bottom_panel.SLDPRT, button_spacer.SLDPRT, dowl_insert.SLDDRW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]
2021-12-18 Upload top panel dimension drawing and laser template drawings
2021-12-18 Add BOM
    [BOM.csv]
2021-12-21 Add pin_assignments/10M50DAF484C7G_fss_top.csv
    [10M50DAF484C7G_fss_top.csv]
2021-12-28 Add FSS assembly project photo to README
